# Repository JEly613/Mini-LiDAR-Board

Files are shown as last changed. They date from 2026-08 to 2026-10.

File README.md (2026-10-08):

# Mini-LiDAR-Board

This project fuses data from LiDAR and IMU measurements to reconstruct internal scans of a room. The LiDAR module is mounted on a custom 4-layer PCB that hosts an STM32 microcontroller and an ICM-42688-P IMU. The data from both sensors is collected by the microcontroller and sent via a custom USB protocol to the host software, where the room is reconstructed.

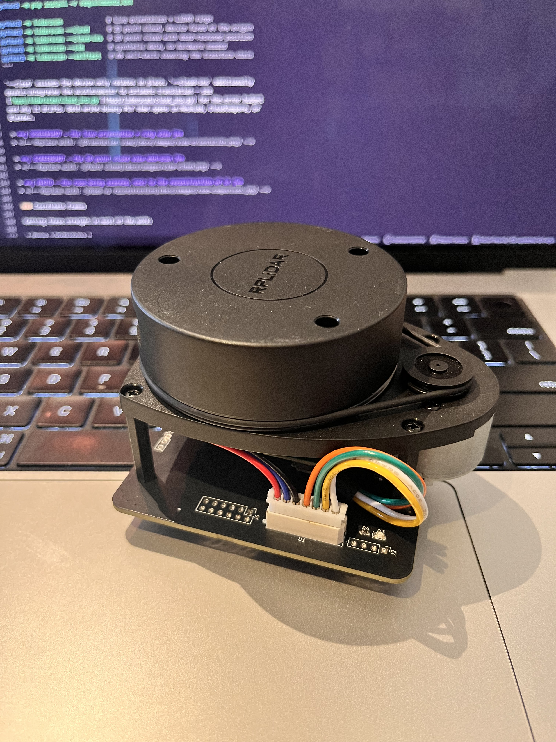
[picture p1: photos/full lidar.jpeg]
The Completed Device


---

## Operation Principle

The board spins a LiDAR module that measures distances in a 2D plane. On its own that only ever produces a flat ring. The on-board IMU tracks how the boardis oriented, so every distance reading can be rotated out of the sensor's 2D plane and into a 3D environment. Tilting the sensor so that all 360 degrees of freedom are covered constructs a full scan of the room.

---

## Hardware

Designed using KiCad.

| | |
|---|---|
| **Board** | 4-layer, 82 × 82 mm, 49 components, 212 vias |
| **Stackup** | `F.Cu` signal · `In1.Cu` GND plane · `In2.Cu` VDD plane · `B.Cu` signal |
| **MCU** | STM32F411CEU6 — QFN-48, 7 × 7 mm, 0.5 mm pitch, 96 MHz |
| **IMU** | TDK ICM-42688-P — LGA-14, 2.5 × 3 mm, on SPI1 |
| **LiDAR** | Slamtec RPLIDAR A1, PWM-driven spindle |
| **Power** | USB-C in, AP2112K-3.3 LDO, 5 V and 3.3 V rails |
| **Clock** | 8 MHz ABM3B crystal → 96 MHz core + exact 48 MHz USB |

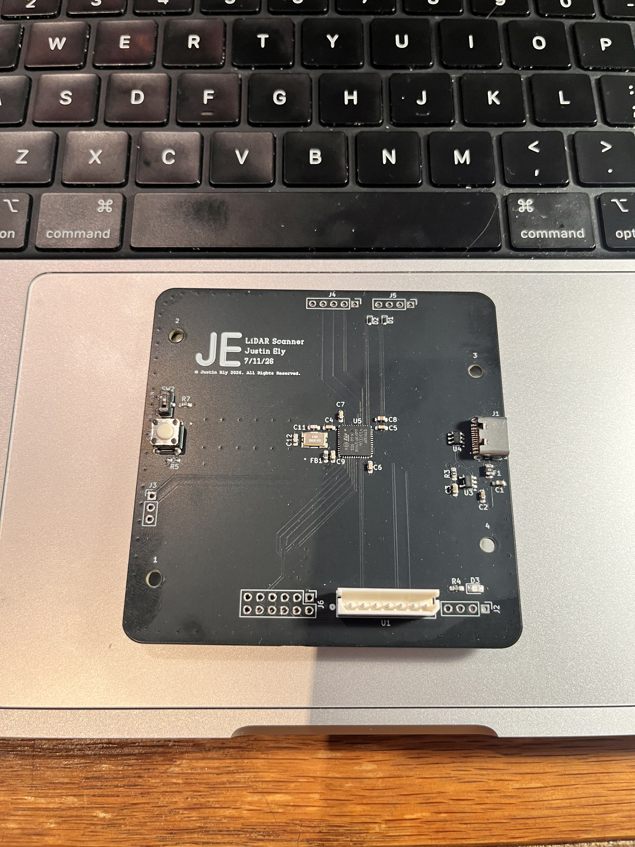
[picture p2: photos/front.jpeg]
Assembled PCB Front Side


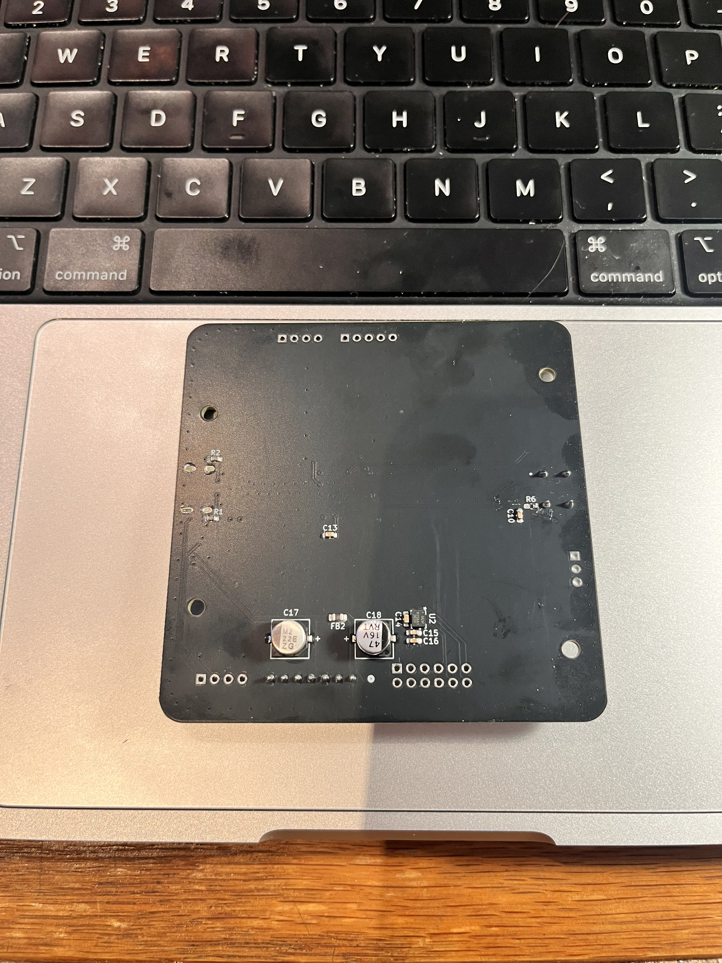
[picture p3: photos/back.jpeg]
Assembled PCB Back Side


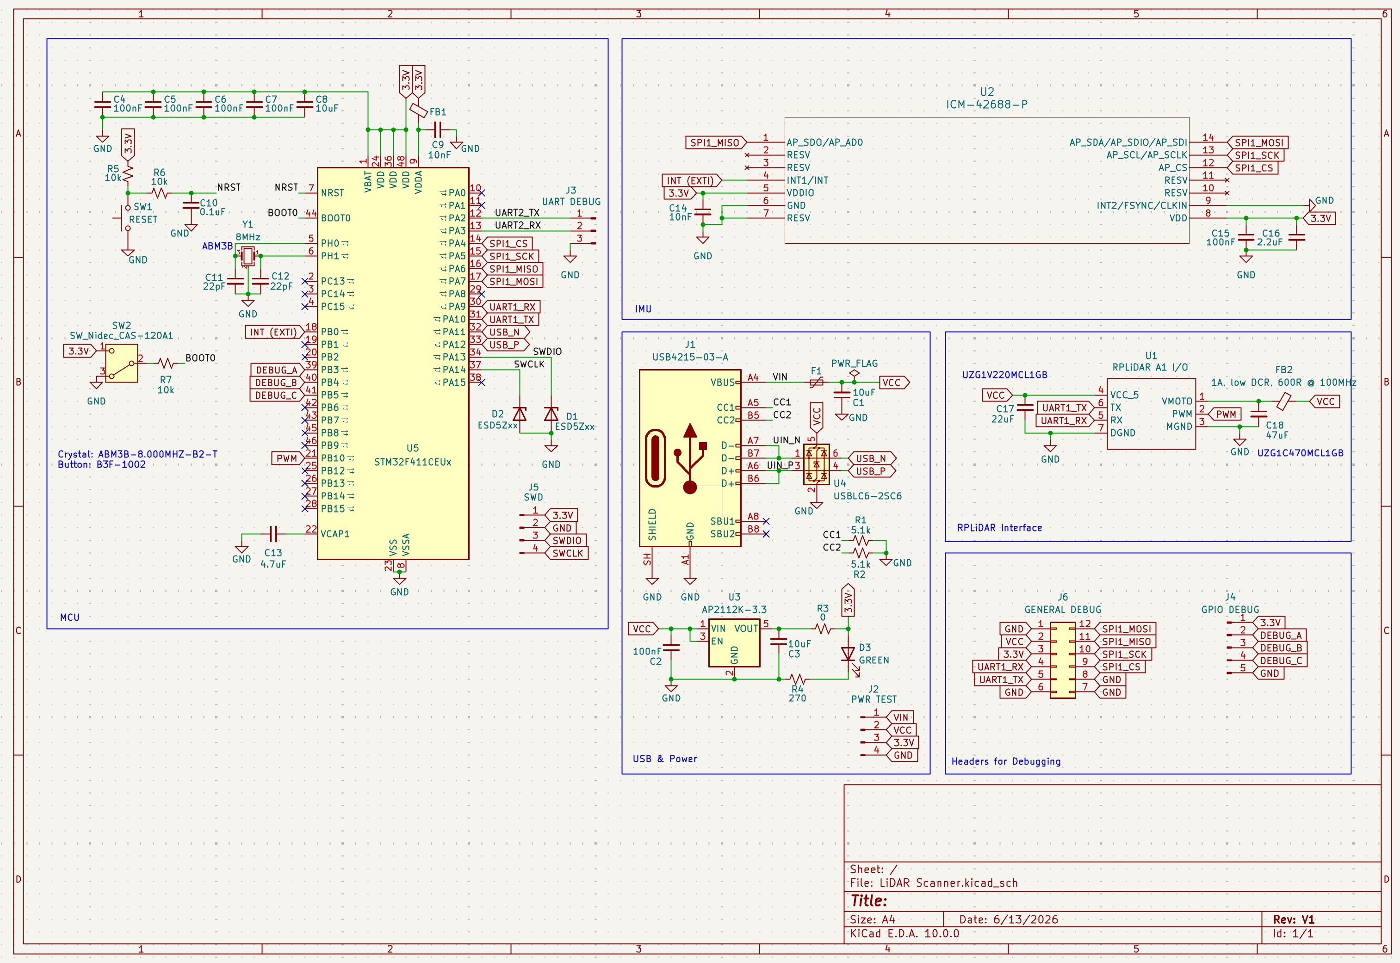
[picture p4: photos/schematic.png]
PCB Schematic


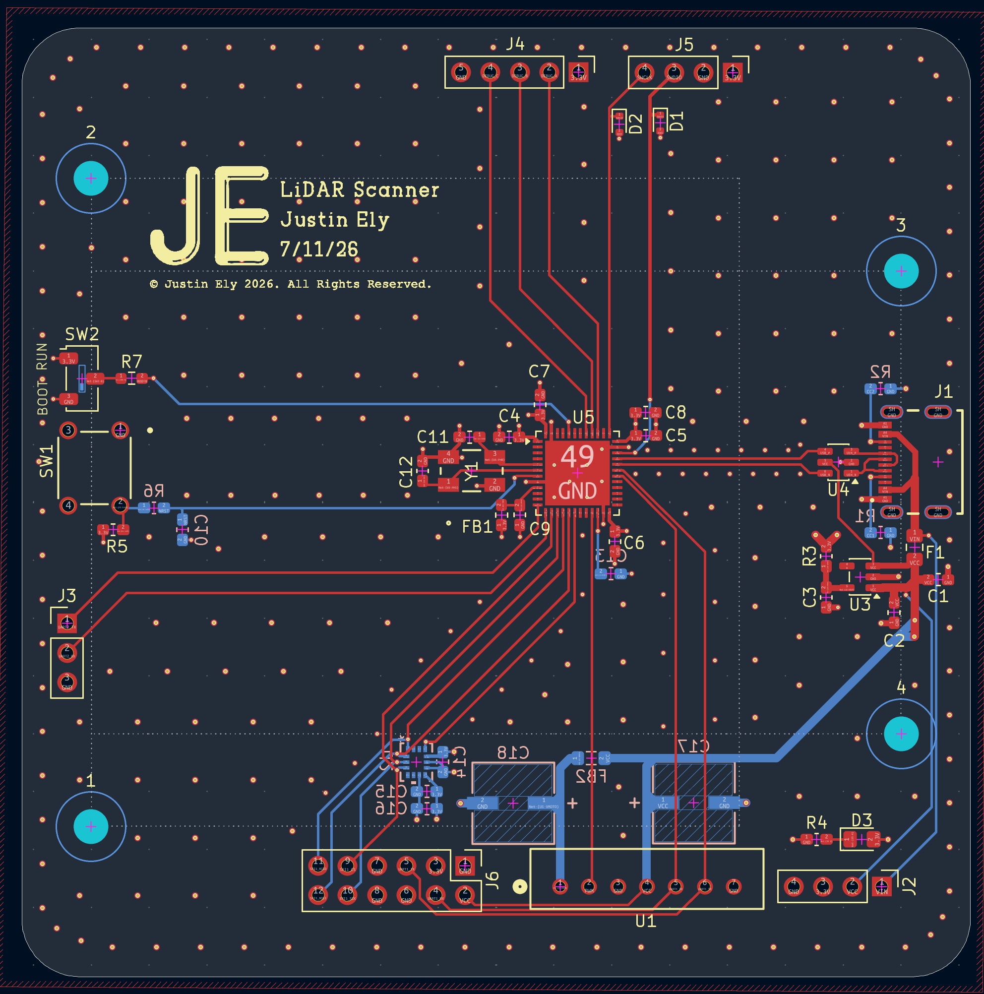
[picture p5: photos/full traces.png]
PCB Layout - Traces


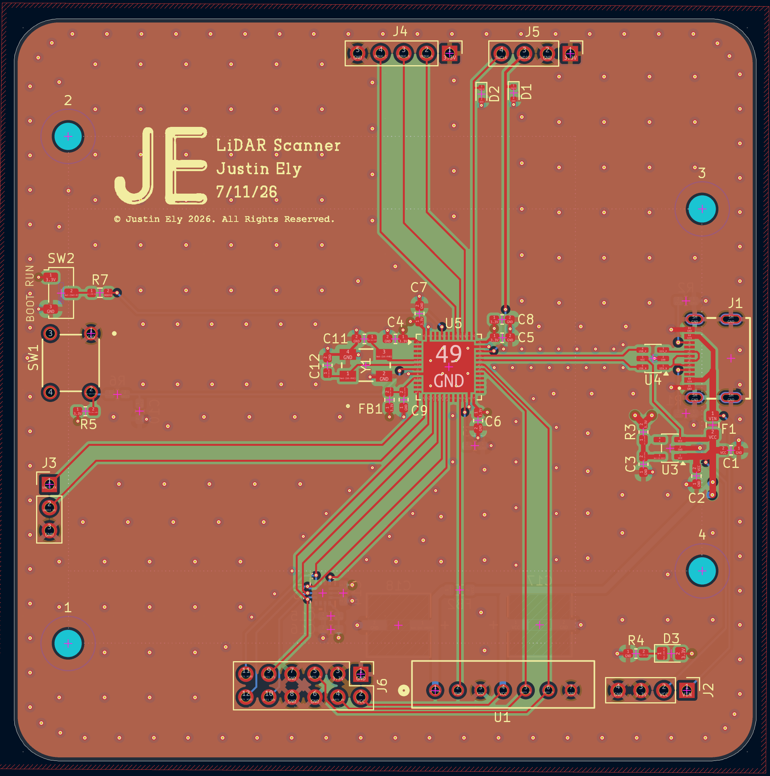
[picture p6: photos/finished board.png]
PCB Layout - Full Stackup


A few notable design decisions:

- **The IMU is mounted on the bottom copper**, rotated −90 degrees. I was worried about the brushed motor on the LiDAR creating noise that would interfere with the IMU, so I shielded it with a few layers of copper. I probably didn't need to but wanted to be safe.
- **The LiDAR motor supply is permanently on** through ferrite bead FB2, with no enable pin. The motor is only driven by the PWM signal, which sometimes causes issues with startup. Next revision I'll add a motor enable.
- **PA9 carries the LiDAR UART**, which means that the MCU can only be flashed through the SWD header.

Gerbers are in:
[`production/`](production/).

---

## Firmware

NOTE: Designed, tested, and validated by me. Implemented with the help of Claude Code.

Register-level bare-metal C with a **12 KB flash image**.

- 96 MHz core from the 8 MHz crystal, with the exact 48 MHz PLLQ that USB needs
- ICM-42688-P at 1 kHz over SPI1 with DMA, triggered by its data-ready interrupt
- 6-DOF Madgwick fusion at the full sample rate, with startup gyro-bias calibration
- RPLIDAR A1 `SCAN` decoding off USART1 with circular DMA and byte-level resync
- TIM2_CH3 PWM spindle control
- CRC-16 framed binary protocol, hardware watchdog, and independent stall
  detection for the IMU, the LiDAR link, and the spindle

Full detail in [`firmware/README.md`](firmware/README.md),
[`firmware/HARDWARE.md`](firmware/HARDWARE.md), and the wire format in
[`firmware/PROTOCOL.md`](firmware/PROTOCOL.md).

### Build and flash

Requires `arm-none-eabi-gcc` and `st-flash` (from stlink-tools).

```bash
cd firmware
make            # builds build/lidar-imu.bin and prints section sizes
make flash      # writes it over SWD
```

---

## Host software

NOTE: Designed, tested, and validated by me. Implemented with the help of Claude Code.

Python 3 with NumPy and matplotlib. Reads the USB CDC stream, parses the binary
protocol, and renders three views.

```bash
cd host
python3 -m pip install -r requirements.txt

python3 -m lidarscan              # live orientation + LiDAR rings
python3 -m lidarscan --cloud      # 3D point cloud, device fixed at the origin
python3 -m lidarscan --cloud-ins  # 3D point cloud with dead-reckoned position
python3 -m lidarscan --sim        # synthetic data, no hardware needed
python3 -m lidarscan --selftest   # 60 self-tests covering the transform chain
```

`--cloud` assumes the device only rotates in place. `--cloud-ins` additionally
double-integrates the accelerometer to estimate translation — see
[`host/lidarscan/cloud_ins.py`](host/lidarscan/cloud_ins.py) for the error budget
and why it drifts. Both write binary PLY that opens in MeshLab, CloudCompare, or
Blender.

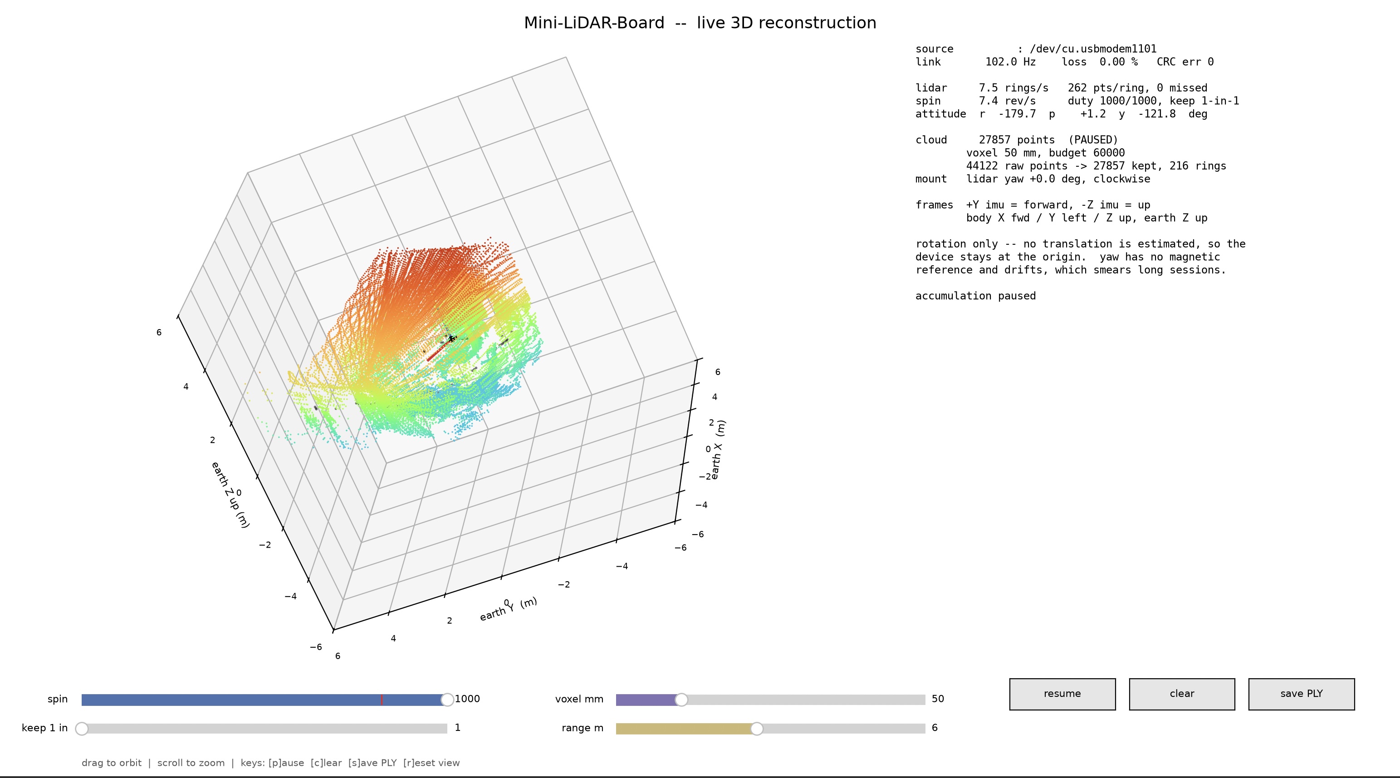
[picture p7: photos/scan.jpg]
Scanning Software


### Coordinate frames

Getting these straight is most of the work:

| Frame | Definition |
|---|---|
| **Sensor** | Raw ICM-42688-P axes. What the Madgwick filter integrates. |
| **Body** | The board: X forward, Y left, Z up. `+Y` sensor is forward, `−Z` sensor is up. |
| **Earth** | Madgwick's output frame, Z up. Yaw has no absolute reference. |
| **LiDAR** | The A1's scan plane, related to the body frame by its physical mounting. |

The A1 is a separate module on a cable, so its orientation relative to the PCB
is mechanical and cannot be known from code. `--lidar-yaw-deg` aligns forward and
`--lidar-ccw` un-mirrors the sweep; set them once for your mounting.

---

## Repository layout

```
firmware/          bare-metal STM32F411 firmware
  src/             16 C source files
  include/         headers, incl. board.h — the authoritative pin map
  cmsis/           vendored ARM CMSIS headers
  PROTOCOL.md      normative wire format
  HARDWARE.md      pin map, DMA allocation, link budget
host/
  lidarscan/       Python host application
    protocol.py    framing, CRC, packet encode/decode
    reader.py      serial + simulated sources
    viz.py         orientation and ring views
    cloud.py       3D reconstruction, rotation only
    cloud_ins.py   3D reconstruction with dead reckoning
production/        gerbers, drill, pick-and-place
docs/images/       photos and screenshots for this README
*.kicad_*          schematic and PCB source
```

---

## Status and known limitations

Working end to end: the board is fabricated, assembled, and validated driving
the IMU, LiDAR, and USB concurrently at 0.00% measured packet loss and 5.6 rev/s
sustained scanning.

Known limits, all understood rather than mysterious:

- **Yaw drifts.** A 6-DOF filter has no magnetic reference, so long sessions
  smear the cloud about the vertical axis. Sweep and look; don't leave it
  accumulating for ten minutes and expect crisp walls.
- **`--cloud-ins` position drifts as t².** Double integration of a MEMS
  accelerometer diverges; zero-velocity updates and bias tracking bound it but
  cannot repeal it. Pause frequently while scanning.
- **Orientation packets are decimated 10:1 without an anti-alias filter**, so
  vibration above 50 Hz aliases into the band the dead-reckoner integrates.
  Averaging the samples in firmware would fix it.
- **The −90° IMU mounting rotation is not separately calibrated** — only the
  Z-flip is handled, via the stated sensor-to-body convention.

---

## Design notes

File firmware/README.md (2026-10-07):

NOTE: Designed, tested, and validated by me. Implemented with the help of Claude Code.

# Mini-LiDAR-Board firmware — IMU orientation + LiDAR rings

Register-level bare-metal C for the STM32F411CEU6 on the custom Mini-LiDAR
scanner board. It reads the on-board ICM-42688-P at 1 kHz, runs a 6-DOF
Madgwick filter, and streams the resulting quaternion to a host over USB
CDC-ACM at ~100 Hz.

It also drives the RPLIDAR A1: TIM2_CH3 PWM on PB10 sets the spindle speed,
USART1 with circular DMA carries the standard `SCAN` stream, and each complete
revolution is forwarded to the host paired with the quaternion at ring-close
time.

**There is no 3D reconstruction in this milestone.** Rings ship in the
sensor's own 2D polar frame. The quaternion travels alongside them, but nothing
rotates anything yet. See [HARDWARE.md](HARDWARE.md).

Host-adjustable at runtime: spindle speed (PWM duty), point decimation, and
scan on/off — see the command table in [PROTOCOL.md](PROTOCOL.md).

Related documents:

* [HARDWARE.md](HARDWARE.md) — verified pin map, IMU quirks, and where the old
  project guide is wrong (**start here**)
* [PROTOCOL.md](PROTOCOL.md) — the binary wire format
* [`../host/`](../host) — the Python visualiser

---

## Requirements

Nothing but the GNU Arm toolchain and `stlink`. No CMake, no STM32Cube, no HAL.
CMSIS core and device headers are vendored into `cmsis/`, so the tree builds
offline.

```
brew install arm-none-eabi-gcc stlink   # already present on this machine
```

The Homebrew `arm-none-eabi-gcc` ships **without newlib**: there is no `libc.a`,
no `<string.h>` and no `<math.h>`. The build is therefore `-ffreestanding
-nostdlib`, `src/util.c` supplies the four `mem*` functions GCC may emit calls
to, and `__builtin_sqrtf` compiles straight to a `VSQRT.F32` instruction, so no
libm is needed.

---

## Build

```
cd firmware
make
```

Produces `build/lidar-imu.elf`, `.bin`, `.hex` and a linker map. The build is
clean under `-Wall -Wextra -Wshadow -Wundef -Wdouble-promotion`.

Other targets:

| target | effect |
|---|---|
| `make flash` | write `build/lidar-imu.bin` to `0x08000000` via `st-flash` and reset |
| `make erase` | full chip erase, if the flash gets into a bad state |
| `make disasm` | annotated disassembly to `build/lidar-imu.lst` |
| `make clean` | remove `build/` |

---

## Wiring the ST-Link to J5

Header **J5** is the SWD port. Pinout, in order:

| J5 pin | signal | ST-Link V2 pin |
|---|---|---|
| 1 | 3V3 | 3.3 V (see note) |
| 2 | GND | GND |
| 3 | SWDIO | SWDIO |
| 4 | SWCLK | SWCLK |

**Note on pin 1.** If the board is powered over its USB-C connector, leave J5.1
disconnected — do not back-feed 3.3 V from the ST-Link into a board that is
already powered. If the board is *not* on USB, connect J5.1 to the ST-Link's
3.3 V output to power it. Never connect J5.1 to the ST-Link's 5 V pin.

Check the probe sees the target before flashing:

```
st-info --probe
```

You should see an `F4` device with 512 KiB of flash. Then:

```
make flash
```

---

## What to expect after flashing

**This board has no GPIO status LEDs.** D3 is a power indicator wired across the
3.3 V rail; the MCU cannot drive it. Nothing blinks. All status is reported over
USB, or on the J4 scope pins.

1. Plug the USB-C cable into a Mac. Within a second or two a serial device
   appears:

   ```
   ls /dev/cu.usbmodem*
   ```

   The device name embeds the STM32's 96-bit unique ID, so two boards on the
   same host get distinct nodes.

2. The firmware immediately sends a `STATUS`/`BOOT` frame, then a
   `STATUS`/`IMU_OK` frame (or an error frame if `WHO_AM_I` did not read
   `0x47`), then `CALIB_START`.

3. **Hold the board still for about two seconds.** It averages 2000 gyro
   samples to measure the zero-rate bias. If it detects motion above 5 °/s it
   retries, up to three times. Then `CALIB_DONE`.

4. From then on it streams `ORIENTATION` frames at ~100 Hz. Run the host app:

   ```
   cd ../host && python3 -m lidarscan
   ```

If you want to see raw bytes rather than run the visualiser, note that the
stream is **binary**, so `cat /dev/cu.usbmodem*` will fill the terminal with
garbage. Use `xxd` or the host app.

### J4 timing pins

Put a logic analyser on J4 to see the firmware's real timing without the USB
link:

| pin | signal | expected |
|---|---|---|
| PB3 | DEBUG_A | toggles on each IMU data-ready → 500 Hz square wave |
| PB4 | DEBUG_B | toggles on each Madgwick update → 500 Hz, phase-shifted from A by the filter latency |
| PB5 | DEBUG_C | toggles on each packet queued → 50 Hz |

If DEBUG_A is flat, the IMU is not asserting INT1. If DEBUG_A runs but DEBUG_B
does not, the main loop is stuck.

### Recovery behaviour

* An independent watchdog (IWDG, ~500 ms nominal) resets the board if the main
  loop stalls. The symptom is the USB serial device disappearing and coming
  back.
* If no IMU data-ready edge arrives for 200 ms, the firmware re-runs
  `icm_init()` and reports `IMU_STALL` then `IMU_RECOVERED`.
* If the 8 MHz crystal fails to start there is no 48 MHz for USB and no way to
  report anything, so the firmware resets. A genuinely dead crystal shows up as
  a boot loop, visible with a scope on PH0.

---

## Source layout

```
firmware/
  Makefile                    plain make, no generator
  stm32f411ce.ld              linker script (512K flash / 128K RAM)
  cmsis/core/                 vendored ARM CMSIS-Core headers
  cmsis/device/               vendored ST device headers (stm32f411xe.h etc.)
  include/, src/
    startup_stm32f411xe.c     vector table + reset entry, written in C
    clock.c                   96 MHz PLL with exact 48 MHz PLLQ for USB
    tim_us.c                  TIM5 as a 32-bit 1 MHz free-running clock
    debug_pins.c              J4 scope pins (the board's only indicators)
    iwdg.c                    independent watchdog
    util.c                    freestanding mem* replacements
    spi1_dma.c                SPI1 + DMA2 Str0/Str3; polled path for config
    icm42688.c                ICM-42688-P driver, EXTI0 data-ready path
    madgwick.c                6-DOF Madgwick filter, runtime-tunable beta
    packet.c                  wire-format serialisers (see PROTOCOL.md)
    pkt_ring.c                frame-granular TX ring, drop-oldest on overflow
    usb_cdc.c                 bare-metal OTG_FS device stack + CDC-ACM class
    main.c                    bring-up, gyro bias calibration, main loop
```

### Interrupt priorities

| priority | source | why |
|---|---|---|
| 1 | EXTI0 (IMU data-ready) | must not be delayed; it only timestamps and starts DMA |
| 1 | DMA2_Stream0 (SPI RX complete) | decodes the sample; same tier as the trigger |
| 3 | OTG_FS | USB can always wait for the IMU, never the other way round |

---

## Verification status

Honest accounting of what has and has not been exercised:

| item | status |
|---|---|
| Compiles and links cleanly, zero warnings under `-Wall -Wextra` | **verified by execution** |
| Flash/RAM footprint fits the part with enormous margin | **verified** (8.6 KiB flash, 5.4 KiB RAM) |
| Register values checked against RM0383 and the ICM-42688-P datasheet | **verified by reading the documents**, not by running |
| Clock tree, SPI/DMA path, IMU configuration, USB CDC enumeration | **written but never run on hardware** |
| Wire format round-trip (firmware layout ↔ host parser) | **verified by execution** — the host test decodes frames byte-identical to the firmware's layout |

The USB CDC stack and the SPI/IMU path are the two places to expect trouble on
first bring-up, in that order.

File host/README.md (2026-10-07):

NOTE: Designed, tested, and validated by me. Implemented with the help of Claude Code.

# Mini-LiDAR-Board host viewer

Live 3D orientation display for the custom Mini-LiDAR scanner board. It opens
the board's USB CDC serial port, parses the binary telemetry stream described in
[`../firmware/PROTOCOL.md`](../firmware/PROTOCOL.md), and draws the board's
current attitude plus roll/pitch/yaw histories and link statistics.

There is **no LiDAR support here yet** — this milestone covers the on-board
ICM-42688-P IMU only. The parser already skips the reserved LiDAR packet types
gracefully, so adding them later will not break anything running today.

---

## Install

numpy and matplotlib are already present in the miniforge3 environment on this
machine. **`pyserial` is the only new dependency**, and it is needed only for
real hardware — `--sim` runs without it:

```
python3 -m pip install pyserial
```

or

```
python3 -m pip install -r requirements.txt
```

Nothing else is required. In particular this app deliberately does **not** use
Open3D, PyQt, pyqtgraph or vispy; none of them are installed, and matplotlib's
3D axes are perfectly adequate here.

---

## Run

```
cd host

python3 -m lidarscan                  # auto-detect /dev/cu.usbmodem*
python3 -m lidarscan --port /dev/cu.usbmodem14201
python3 -m lidarscan --sim            # synthetic data, no hardware needed
python3 -m lidarscan --selftest       # protocol + geometry checks, then exit
```

Useful flags:

| flag | effect |
|---|---|
| `--sim` | synthesise a rotating quaternion instead of reading hardware |
| `--sim-rate HZ` | simulated packet rate (default 100) |
| `--sim-corrupt N` | corrupt every Nth simulated frame, to exercise CRC + resync |
| `--sim-drop N` | drop every Nth simulated frame, to exercise the loss statistic |
| `--duration SECONDS` | exit automatically after this long |
| `--headless` | render with Agg, open no window (works over SSH / in CI) |
| `--save FILE.png` | write a PNG of the final frame |
| `--fps N` | redraw rate, default 30 |
| `--list-ports` | print candidate serial devices and exit |
| `--selftest` | run the built-in checks and exit |

Example that produces a screenshot with no hardware and terminates on its own:

```
python3 -m lidarscan --sim --headless --duration 8 --save shot.png
```

---

## What the display shows

**Left — 3D attitude.** A wireframe of the board (with a wedge marking the
USB-connector end so its heading is unambiguous) plus an RGB body-axis triad:
X red, Y green, Z blue. The grey square is the earth-horizontal plane, so
"level" is obvious at a glance.

**Top right — roll / pitch / yaw** over the last 10 seconds of device time. The
vertical jumps in yaw are the ±180° wrap, not a glitch.

**Bottom right — live statistics:**

| line | meaning |
|---|---|
| `rate` | orientation packets per second, measured over a 1 s sliding window |
| `loss` | derived from gaps in the device's own `sample_count`, not from counting arrivals — so it catches packets that never left the device |
| `dev drops` | frames the *device* discarded because its TX ring overflowed |
| `CRC err / resync / bad hdr` | parser health |
| `quat`, `rpy`, `accel`, `gyro`, `temp` | current sensor state |
| `gyro bias` | `calibrating`, `valid`, or `NOT CALIBRATED` |

Yaw drifts. There is no magnetometer on this board, so the filter is the 6-DOF
IMU-only Madgwick variant: roll and pitch are gravity-referenced and stable,
yaw is dead-reckoned from gyro Z. That is a property of the hardware.

---

## First run with real hardware

1. Flash the board (`cd ../firmware && make flash`) and plug in USB-C.
2. `python3 -m lidarscan --list-ports` should show a `/dev/cu.usbmodem…` node.
   Its suffix embeds the STM32's unique ID, so two boards get distinct names.
3. `python3 -m lidarscan`. The status panel will show `BOOT`, then `IMU_OK`,
   then `CALIB_START`.
4. **Hold the board still for ~2 seconds** while it measures the gyro bias.
   You will see `CALIB_DONE` and `gyro bias: valid`.
5. Pick it up and move it. The 3D board should follow.

If `gyro bias` stays `NOT CALIBRATED`, the board was moving during calibration;
put it down and it will have retried up to three times, or you can power-cycle.

### Troubleshooting

| symptom | likely cause |
|---|---|
| no `/dev/cu.usbmodem*` | board not enumerating — check the USB cable is a data cable, and see the firmware README's notes on the OTG_FS bring-up |
| `IMU_WHO_AM_I_FAIL` in the status log | SPI is working but the part did not answer `0x47` — check U2 orientation and the PA4 chip select |
| `IMU_NO_RESPONSE` | no SPI answer at all — check the IMU's 3.3 V rails and MISO on PA6 |
| high `CRC err` and rising `discarded` | electrical noise or a firmware framing bug; the parser recovers, but the numbers tell you it happened |
| `loss` climbing with `dev drops` climbing | the host is not reading fast enough; close other consumers of the port |
| `loss` climbing with `dev drops` at 0 | packets are being lost on the USB link itself |

---

## Layout

```
host/
  requirements.txt
  lidarscan/
    __init__.py
    __main__.py    CLI, argument parsing, and the built-in self-test
    protocol.py    frame codec + resynchronising parser (from PROTOCOL.md)
    reader.py      background ingestion thread; serial and simulated sources
    viz.py         matplotlib 3D view, time series and statistics panel
```

`protocol.py` and the firmware's `packet.c` are both written from
`firmware/PROTOCOL.md`. They are cross-checked: compiling `packet.c` natively
and feeding its output to `protocol.py` reproduces the values byte-for-byte, and
re-encoding from Python reproduces the firmware's bytes exactly.

---

## Self-test

`python3 -m lidarscan --selftest` runs 18 checks with no hardware:

* the CRC's published check value (`0x29B1` for `"123456789"`);
* frame sizes match `PROTOCOL.md` (68 B orientation, 52 B status);
* encode → parse → decode round-trips;
* resynchronisation past leading garbage;
* a corrupted frame is rejected and the *next* one still accepted;
* byte-at-a-time feeding gives the same result as one big chunk;
* reserved LiDAR packet types are passed through, not treated as corruption;
* a frame split across two reads reassembles;
* the view's rotation matrix is a proper rotation (orthonormal, det +1);
* a +90° yaw maps body X onto earth Y;
* the attitude the view would draw matches the simulator's ground truth to
  within 6e-8.

---

## LiDAR view and controls

The window shows three panels: board attitude in 3D, the current LiDAR
revolution in the sensor's own polar frame, and roll/pitch/yaw over time, plus
a live statistics panel.

**Rings are drawn flat, in the sensor frame.** They are not rotated by the IMU
quaternion — that is the next milestone. The quaternion is carried in every
scan packet already.

Three controls sit along the bottom, and all three change what the *hardware*
does, not just the plot:

| control | effect |
|---|---|
| **spin** | PWM duty on PB10 in permille (0–1000). 0 stops the spindle; below ~250 it stalls rather than turning slowly. |
| **keep 1 in N** | on-device decimation, applied before the packet is built — so it genuinely shrinks the USB traffic. |
| **scan: on/off** | sends the LiDAR `STOP` / `SCAN` command. Does not touch the motor. |

Because the A1's sample rate is fixed (~1954 samples/s measured, capped by the
115200-baud link), spinning slower yields *more* points per revolution rather
than more points per second:

| spin | rings/s | points/ring |
|---|---|---|
| duty 350 | ~2 | ~920 |
| duty 600 | 3.5 | ~550 |
| duty 820 (default) | 5.6 | ~350 |
| duty 900 | 6.2 | ~313 |

600 was the original default and turned out to be marginal — the spindle ran
below its rated speed and eventually stalled during a long session. 820 puts it
on the A1's nominal 5.5 rev/s.

Below ~2 rev/s a revolution exceeds the firmware's 1024-point cap; the plot
then labels the ring `[TRUNCATED]`.

A distance of 0 means "no return" on that ray, not zero range. Those points are
masked out of the plot and counted separately in the caption.

`--sim` synthesises a 4 × 3 m room with a pillar in it, at whatever density the
current simulated spin and decimation imply, so the whole UI including the
controls can be exercised with no hardware attached.

---

## 3D reconstruction (`--cloud`)

```
python3 -m lidarscan --cloud
python3 -m lidarscan --sim --cloud          # no hardware needed
```

Each LiDAR revolution is rotated into world space by the quaternion carried in
that same scan packet — the attitude at the instant the revolution closed — and
accumulated into a voxel-thinned point cloud centred on the device.

**Drag to orbit, scroll to zoom.** Keys: `p` pause accumulation, `c` clear,
`s` save PLY, `r` reset the view. Sliders set spindle speed, decimation, voxel
size and the display cube; buttons pause / clear / save.

### Frames

| frame | definition |
|---|---|
| sensor | raw ICM-42688-P axes; what Madgwick integrates |
| body | **+Y_imu = forward, −Z_imu = up** → X forward, Y left, Z up |
| earth | Madgwick's output frame, Z up. Yaw is free and drifts |

The sensor→body matrix is `[[0,1,0],[1,0,0],[0,0,−1]]` — det +1, so a rotation
and not a mirror. A point at range `d` and angle `θ` becomes
`R_es · M · (d cos θ, d sin θ, 0)`.

### Rotate the device, or you get a flat ring

**No translation is estimated.** The device is assumed to rotate in place, so
it stays at the origin. A stationary board therefore produces exactly one
horizontal ring, no matter how long you leave it running — which is correct,
not a bug. Tilt and sweep the unit to paint a 3D scene.

Measured with the board sitting still and level: 11 797 raw points collapsed to
202 voxels spanning just 108 mm in Z across a 4.2 m radius — a flat disc, as it
should be.

Because yaw has no magnetic reference it drifts, so a long session smears the
cloud about the vertical axis. Sweep and look; don't leave it accumulating for
ten minutes and expect crisp walls.

### Mounting the LiDAR

The A1 is a separate module on a cable, so its orientation relative to the PCB
is a mechanical fact the code cannot know. Two options cover it:

- `--lidar-yaw-deg D` — rotate the scan about the board's up axis until a
  landmark you know is dead ahead appears at the front of the cloud.
- `--lidar-ccw` — flip the sweep direction if the cloud comes out mirrored.

### Keeping it responsive

matplotlib is not a point-cloud engine. `--voxel-mm` (default 50) and
`--max-points` (default 60 000) are what keep the frame rate usable; past
roughly 100 000 points a redraw costs more than the frame interval. Repeated
sweeps of the same wall collapse onto the same voxels, so the cloud stops
growing once the room is covered.

`--save-ply PATH` writes a binary PLY (metres, colour by height) on exit, which
MeshLab, CloudCompare and Blender all open directly.

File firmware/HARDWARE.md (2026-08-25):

# Verified hardware notes — Mini-LiDAR-Board

Everything in this file was read out of the project's KiCad schematic and PCB
(`LiDAR Scanner.kicad_sch`, `LiDAR Scanner.kicad_pcb`) rather than out of
`Lidar Project Guide.md`. **Where the two disagree, this file is right and the
guide is out of date.** The list of disagreements is in the last section.

---

## MCU

| item | value |
|---|---|
| Part | STM32F411CEU6 |
| Package | **UFQFPN-48** (4 mm × 4 mm QFN) |
| Flash / SRAM | 512 KiB / 128 KiB |
| Core | Cortex-M4F, single-precision FPU |
| HSE | 8 MHz crystal Y1 on PH0/PH1, 22 pF load caps |
| LSE | **none fitted** — no 32.768 kHz crystal on this board |
| VCAP1 | pin 22 |

Clock configuration used by this firmware (see `src/clock.c`):

```
HSE 8 MHz -> PLL(M=4, N=192, P=4, Q=8)
  VCO in   2 MHz      (RM0383: must be 1-2 MHz)
  VCO out  384 MHz    (RM0383: must be 100-432 MHz)
  SYSCLK    96 MHz    (F411 limit 100 MHz)
  PLLQ      48 MHz    exact, for USB OTG_FS
AHB /1  ->  HCLK  96 MHz
APB1 /2 ->  PCLK1 48 MHz   (F411 limit 50 MHz), APB1 timers 96 MHz
APB2 /1 ->  PCLK2 96 MHz   (F411 limit 100 MHz)
Flash: 3 wait states, prefetch + I-cache + D-cache on
Power: regulator voltage Scale 1 (required above 84 MHz)
```

---

## Pin map (authoritative)

| Function | Pin | Notes |
|---|---|---|
| IMU SPI1_CS | PA4 | software-controlled GPIO chip select, not hardware NSS |
| IMU SPI1_SCK | PA5 | AF5 |
| IMU SPI1_MISO | PA6 | AF5 |
| IMU SPI1_MOSI | PA7 | AF5 |
| IMU INT1 | **PB0** | EXTI0, data-ready interrupt |
| USB D− | PA11 | USB_OTG_FS, AF10 |
| USB D+ | PA12 | USB_OTG_FS, AF10 |
| SWDIO / SWCLK | PA13 / PA14 | header J5 (1 = 3V3, 2 = GND, 3 = SWDIO, 4 = SWCLK) |
| Debug UART2 TX / RX | PA2 / PA3 | header J3 (1 = TX, 2 = RX, 3 = GND), AF7 |
| DEBUG_A / B / C | PB3 / PB4 / PB5 | header J4, scope/logic-analyser timing pins |
| LiDAR UART1 TX / RX | PA9 / PA10 | **out of scope this milestone — left unconfigured** |
| LiDAR motor PWM | PB10 | TIM2_CH3 — **out of scope, left unconfigured (input, no drive)** |

### PB3 / PB4 are JTAG pins at reset

They come out of reset as JTDO-TRACESWO and NJTRST. Driving them as the J4
timing outputs disables the JTAG-DP. That is harmless here because J5 exposes
**SWD only**, and SWD (PA13/PA14) keeps working. The cost is that SWO trace is
unavailable.

---

## IMU — U2, TDK InvenSense ICM-42688-P, LGA-14

| item | value |
|---|---|
| VDD / VDDIO | both 3.3 V |
| Bus | **SPI only** — there is no I²C to the IMU on this board |
| WHO_AM_I (reg 0x75) | must read `0x47` |
| INT1 | pin 14 → PB0 |
| INT2 / FSYNC / CLKIN (pin 9) | **hard-tied to GND** |
| RESV pin 7 | tied to GND |
| RESV pins 2, 3, 10, 11 | unconnected |

### Consequences of pin 9 being grounded

1. **INT2 and FSYNC are unavailable.** INT1 on PB0 is the only interrupt path.
2. INT2 must never be configured as a push-pull output — it would drive into a
   ground short. `src/icm42688.c` leaves the INT2 half of `INT_CONFIG` (bits
   5:3) at its reset value: open drain, active low.
3. `TMST_CONFIG.TMST_FSYNC_EN` comes out of reset **set**, which makes the part
   interpret the grounded pin as an FSYNC input and overwrite the low byte of
   gyro X with an FSYNC timestamp. The firmware explicitly clears it during
   init. This is easy to miss and produces a subtly wrong gyro X axis.

### Other datasheet details the driver depends on

* `INT_CONFIG1` bit 4 `INT_ASYNC_RESET` comes out of reset **set**, and the
  datasheet instructs the user to clear it "for proper INT1 and INT2 pin
  operation". Left at 1, interrupt pulses go missing. The firmware writes
  `INT_CONFIG1 = 0x00`.
* After writing `PWR_MGMT0`, no register write may be issued for 200 µs; the
  gyro additionally needs up to ~30 ms to start.
* Sensitivity at the configured ranges: gyro ±500 dps → 65.5 LSB/dps;
  accel ±8 g → 4096 LSB/g; temperature → `°C = raw/132.48 + 25`.
* Maximum SPI clock is 24 MHz. The firmware uses ~1.5 MHz for configuration
  writes and 12 MHz for the data burst.

---

## THERE ARE NO GPIO STATUS LEDs

This is the single most important thing to know before writing firmware for
this board.

* **D3 is a green power LED wired directly across the 3.3 V rail through R4.**
  It has no MCU connection whatsoever. It is on whenever the board has power.
* There is no IMU LED, no LIDAR LED and no STATUS LED, despite what the project
  guide describes. They were never built.

Every piece of firmware state must therefore be reported either:

1. over the USB data link, as a `STATUS` packet (see `PROTOCOL.md`), or
2. as an edge on DEBUG_A/B/C (PB3/PB4/PB5, header J4) for a scope or logic
   analyser.

There is no blink code anywhere in this project, and there cannot be. Any
future contributor who "adds an LED heartbeat" is writing to a pin that does
not exist.

---

## DMA allocation and the reservation for LiDAR

On the STM32F411 (RM0383 Table 28, DMA2 request mapping):

```
SPI1_RX   : DMA2 Stream 0 ch 3   or   DMA2 Stream 2 ch 3
SPI1_TX   : DMA2 Stream 3 ch 3   or   DMA2 Stream 5 ch 3
USART1_RX : DMA2 Stream 2 ch 4   or   DMA2 Stream 5 ch 4
```

USART1_RX — which the LiDAR will need, because an RPLIDAR pushes a continuous
scan stream that cannot be serviced byte-by-byte alongside a 1 kHz IMU — can
only live on Stream 2 or Stream 5. This firmware therefore takes **Stream 0 for
SPI1_RX and Stream 3 for SPI1_TX**, leaving both USART1_RX options free.
Choosing Stream 2 or Stream 5 for SPI would work fine today and force a rework
later.

---

## Deviations from `Lidar Project Guide.md`

| The guide says | Reality |
|---|---|
| MCU is in an **LQFP48** package | It is **UFQFPN-48** |
| IMU INT2 / FSYNC usable | Pin 9 is **hard-tied to GND**; INT2 and FSYNC do not exist on this board |
| IMU, LIDAR and STATUS **LEDs** on GPIOs | **No GPIO LEDs exist.** D3 is a power-rail-only indicator with no MCU connection |
| — | The guide does not mention that `TMST_CONFIG.TMST_FSYNC_EN` must be cleared because of the grounded FSYNC pin |

Do not "fix" the firmware to match the guide.

---

## LiDAR wiring (added in the LiDAR milestone)

Connector **U1** (Molex 22035075) carries the RPLIDAR A1:

| U1 pin | net | goes to | note |
|---|---|---|---|
| 1 | `Net-(U1-VMOTO)` | 5 V via ferrite bead **FB2**, 47 µF bulk (C18) | motor supply |
| 2 | `PWM` | **PB10**, TIM2_CH3, AF1 | spindle speed |
| 3 | `MGND` | GND | motor ground |
| 4 | `VCC` | 5 V via polyfuse F1 | logic supply |
| 5 | `UART1_RX` | **PA9** = USART1_**TX** | MCU → LiDAR |
| 6 | `UART1_TX` | **PA10** = USART1_**RX** | LiDAR → MCU |
| 7 | `DGND` | GND | |

Three things here differ from the project guide and matter for firmware:

1. **There is no motor enable GPIO and no LiDAR enable jumper.** VMOTO is
   hard-wired to 5 V through FB2, so the spindle is powered whenever the board
   is. PWM duty on PB10 is the *only* control over the motor; 0 % is the only
   way to stop it. The guide describes a solder jumper on a "motor enable GPIO
   line" — it was never built.

2. **The UART net names are from the LiDAR's point of view.** The net called
   `UART1_RX` lands on PA9, which is USART1_**TX**. The wiring is correct; only
   the labels invite a mis-read.

3. **PA9 is also the OTG_FS VBUS sense pin**, and it is used for the LiDAR
   UART here. `GCCFG.NOVBUSSENS` must stay set or USB will not enumerate. This
   was already true before the LiDAR existed, but it is now load-bearing for
   two subsystems rather than one.

### Link budget

The A1 runs at 115200 baud and standard `SCAN` mode spends 5 bytes per
measurement, so the wire caps out at ~2300 samples/s no matter what the sensor
can do internally. Measured on this board: **1954 samples/s**. Spindle speed
therefore trades rings/s against points/ring:

| PWM duty | measured spin | points/ring |
|---|---|---|
| 350 | ~2 rev/s | ~920 |
| 600 | 3.5 rev/s | ~550 |
| 820 (default) | 5.6 rev/s | ~350 |
| 900 | 6.2 rev/s | ~313 |

The default was originally 600. That runs the spindle well below its rated
5.5 rev/s, and during a long session it stalled outright — hence 820.

### Two different LiDAR stalls

Worth knowing because they need different watchdogs, and only one of them is
obvious:

1. **The device goes quiet.** No measurement nodes arrive. Caught by watching
   `rplidar_last_node_us()`.
2. **The spindle stops but the device keeps talking.** The A1 goes on streaming
   measurement nodes at a frozen angle, so the node watchdog stays happy
   forever while no revolution ever closes. This is the one that actually bit
   us. Caught separately by watching `rplidar_last_ring_us()`.

Recovery for (2) kicks the motor to full duty for 400 ms before restoring the
commanded duty — static friction takes more torque to break than rotation takes
to sustain — then re-arms the UART DMA and restarts the scan.

Below about 2 rev/s a revolution exceeds the firmware's 1024-point cap and the
ring is truncated (flagged, not silent).

### DMA map

| request | stream | why |
|---|---|---|
| SPI1_RX | DMA2 Stream 0 ch 3 | leaves both USART1_RX options free |
| SPI1_TX | DMA2 Stream 3 ch 3 | |
| USART1_RX | DMA2 Stream 5 ch 4 | circular, never serviced on a deadline |

USART1_RX can only live on Stream 2 or Stream 5, and SPI1_RX only on Stream 0
or Stream 2. Putting SPI1 on Stream 0 during the IMU milestone is what made
this conflict-free; Stream 2 is still spare.

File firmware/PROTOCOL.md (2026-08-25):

# Mini-LiDAR-Board wire protocol v1

This document is the **normative** definition of the binary link between the
board and the host. Both implementations are written from this table:

| Side | File |
|---|---|
| Firmware serialiser | `firmware/src/packet.c`, `firmware/include/packet.h` |
| Host parser | `host/lidarscan/protocol.py` |

If you change the format, change all three, and bump `version`.

The transport is a USB CDC-ACM (virtual serial) link. It is a **byte stream**,
not a message-oriented one — USB packet boundaries are not frame boundaries, so
the parser must find frames by scanning for the sync pattern and validating the
CRC. Never assume one read returns exactly one frame.

---

## 1. Frame layout

```
 offset  size  field      description
 ------  ----  ---------  ------------------------------------------------
      0     1  sync0      0xA5
      1     1  sync1      0x5A
      2     1  version    0x01 for this document
      3     1  type       see section 2
      4     2  length     payload length in bytes (uint16)
      6     N  payload    type-specific, N == length
    6+N     2  crc16      CRC-16/CCITT-FALSE over bytes [2 .. 6+N-1]
```

Total frame size is `8 + length`.

### Endianness

**Everything multi-byte is little-endian.** That includes `length`, `crc16`, all
integers in payloads, and all `float32` values (IEEE-754 binary32, stored
little-endian — i.e. what `struct.unpack('<f', ...)` reads and what a
Cortex-M4 or an x86/ARM host stores natively). No field anywhere in this
protocol is big-endian.

(The ICM-42688-P itself delivers big-endian sensor words on the SPI bus. That
is a detail entirely internal to the firmware; nothing big-endian reaches the
wire.)

### Checksum

CRC-16/CCITT-FALSE, also catalogued as CRC-16/IBM-3740:

| parameter | value |
|---|---|
| polynomial | `0x1021` |
| initial value | `0xFFFF` |
| input reflected | no |
| output reflected | no |
| final XOR | `0x0000` |

It covers `version`, `type`, `length` and the payload — bytes 2 through
`6+N-1` — but **not** the two sync bytes. The sync bytes are a resynchronisation
marker rather than data; including them would add nothing, whereas covering
`length` means a corrupted length can never make a receiver accept a mis-sized
frame.

### Parsing rules

1. Scan for `A5 5A`.
2. Read the 4 remaining header bytes. Reject (and resume scanning from the byte
   after `sync0`) if `version != 0x01` or `length > 128`.
3. Wait for `length + 2` more bytes.
4. Verify the CRC. On mismatch, discard and resume scanning from the byte after
   `sync0` — a false sync inside a payload is the normal cause.
5. Dispatch on `type`. **Unknown types must be skipped, not treated as an
   error**: that is what makes the format extensible.

---

## 2. Packet types

| range | direction | meaning |
|---|---|---|
| `0x01`–`0x0F` | device → host | IMU / orientation telemetry (this milestone) |
| `0x10`–`0x1F` | device → host | **reserved for LiDAR**, not implemented |
| `0x80`–`0x8F` | host → device | commands |

Assigned:

| type | name | payload | frame |
|---|---|---|---|
| `0x01` | `ORIENTATION` | 60 B | 68 B |
| `0x02` | `STATUS` | 44 B | 52 B |
| `0x10` | `LIDAR_SCAN` — **reserved, unimplemented** | — | — |
| `0x11` | `LIDAR_POINT` — **reserved, unimplemented** | — | — |
| `0x80` | `CMD_SET_BETA` | 4 B | 12 B |
| `0x81` | `CMD_RECALIBRATE` | 0 B | 8 B |
| `0x82` | `CMD_PING` | 0 B | 8 B |

Nothing in this firmware emits or parses `0x10`/`0x11`. They exist so that the
numbering is settled before a second data stream is added, and so the host
parser can already be written to ignore them gracefully.

---

## 3. `0x01` ORIENTATION — 60-byte payload

Emitted at ~100 Hz (every 10th 1 kHz filter update).

| offset | type | field | units / notes |
|---|---|---|---|
| 0 | `uint32` | `t_us` | device timestamp of the IMU sample, microseconds |
| 4 | `float32` | `q0` | quaternion scalar part (w) |
| 8 | `float32` | `q1` | quaternion x |
| 12 | `float32` | `q2` | quaternion y |
| 16 | `float32` | `q3` | quaternion z |
| 20 | `float32` | `ax` | accelerometer X, **g** |
| 24 | `float32` | `ay` | accelerometer Y, g |
| 28 | `float32` | `az` | accelerometer Z, g |
| 32 | `float32` | `gx` | gyroscope X, **deg/s**, bias removed |
| 36 | `float32` | `gy` | gyroscope Y, deg/s, bias removed |
| 40 | `float32` | `gz` | gyroscope Z, deg/s, bias removed |
| 44 | `float32` | `temp_c` | IMU die temperature, °C |
| 48 | `uint32` | `sample_count` | IMU samples read since boot |
| 52 | `uint32` | `drop_count` | frames discarded by the TX ring buffer |
| 56 | `uint16` | `imu_odr_hz` | configured IMU output data rate (1000) |
| 58 | `uint8` | `flags` | see section 5 |
| 59 | `uint8` | *reserved* | always 0 |

The quaternion is a **unit** quaternion describing the rotation from the sensor
frame to the earth frame, in Madgwick's `(w, x, y, z)` order.

### Timestamps

`t_us` comes from a free-running 32-bit 1 MHz timer (TIM5). It **wraps every
2³² µs ≈ 4295 s ≈ 71.6 minutes**. Hosts that need a monotonic timeline must
unwrap it themselves; the reference host parser does, by adding 2³² whenever a
timestamp goes backwards.

### Drift caveat

There is no magnetometer on this board, so the filter is the 6-DOF IMU-only
Madgwick variant. Roll and pitch are gravity-referenced and drift-free. **Yaw is
dead-reckoned from gyro Z and will drift** — typically a few degrees per minute
after bias calibration. This is a property of the sensor set, not a bug.

---

## 4. `0x02` STATUS — 44-byte payload

Emitted asynchronously on boot, on IMU init success/failure, around gyro
calibration, on stall detection and recovery, and in reply to `CMD_PING`.

| offset | type | field | notes |
|---|---|---|---|
| 0 | `uint32` | `t_us` | device timestamp, microseconds |
| 4 | `uint32` | `uptime_ms` | milliseconds since boot |
| 8 | `uint8` | `code` | see below |
| 9 | `uint8` | `who_am_i` | last WHO_AM_I byte read from the IMU (0x47 = OK) |
| 10 | `uint8` | `flags` | see section 5 |
| 11 | `uint8` | *reserved* | always 0 |
| 12 | `char[32]` | `msg` | NUL-padded ASCII, **not guaranteed NUL-terminated** |

Status codes:

| code | name | meaning |
|---|---|---|
| 0 | `BOOT` | clocks and USB are up |
| 1 | `IMU_OK` | ICM-42688-P identified and configured |
| 2 | `IMU_WHO_AM_I_FAIL` | device answered, but not with `0x47` |
| 3 | `IMU_NO_RESPONSE` | SPI reads returned only `0x00`/`0xFF` |
| 4 | `CALIB_START` | gyro bias calibration beginning (hold still) |
| 5 | `CALIB_DONE` | bias captured |
| 6 | `IMU_STALL` | no data-ready edge for 200 ms |
| 7 | `IMU_RECOVERED` | IMU re-initialised after a stall |
| 8 | `PONG` | reply to `CMD_PING` |
| 9 | `BETA_CHANGED` | filter gain updated |

---

## 5. Flags byte

Present in both `ORIENTATION` and `STATUS`.

| bit | mask | name | meaning |
|---|---|---|---|
| 0 | `0x01` | `IMU_OK` | IMU identified and streaming |
| 1 | `0x02` | `BIAS_VALID` | gyro bias calibration completed successfully |
| 2 | `0x04` | `USB_CONFIGURED` | host has issued SET_CONFIGURATION |
| 3 | `0x08` | `CALIBRATING` | bias calibration in progress / never completed |
| 4 | `0x10` | `STALL_RECOVERED` | at least one IMU stall recovery has occurred |

---

## 6. Host → device commands

Same framing. The firmware validates sync, version, length and CRC, and
silently ignores anything that fails or that carries an unknown type. Commands
must arrive as a single USB packet (≤ 64 bytes), which every command in this
version comfortably satisfies.

| type | name | payload |
|---|---|---|
| `0x80` | `CMD_SET_BETA` | `float32` — new Madgwick gain, accepted if `0 ≤ β ≤ 10` and not NaN |
| `0x81` | `CMD_RECALIBRATE` | none — restarts gyro bias calibration; hold the board still |
| `0x82` | `CMD_PING` | none — answered with a `STATUS`/`PONG` |
| `0x83` | `CMD_SET_MOTOR` | `uint16` — spindle PWM duty in permille, 0…1000. 0 stops the motor; below ~250 it stalls rather than turning slowly |
| `0x84` | `CMD_SET_DECIM` | `uint8` — keep 1 LiDAR point in N, 1…16. Applied on the device, before the packet is built |
| `0x85` | `CMD_LIDAR_ENABLE` | `uint8` — 0 sends the LiDAR `STOP` command, 1 re-runs health check + `SCAN`. Does not touch the motor |

---

## 7. LiDAR scan packet — type `0x10`

One packet per complete revolution of the RPLIDAR A1. A fixed 40-byte header
followed by `point_count` × 4 bytes, so the frame length is variable and the
reader must size the point array from `point_count`.

| off | size | field | notes |
|---|---|---|---|
| 0 | 4 | `t_us` | device microseconds when the revolution closed |
| 4 | 4 | `seq` | revolutions since scanning started; gaps mean lost packets |
| 8 | 16 | `q[4]` | `float32` w, x, y, z — board attitude at `t_us` |
| 24 | 4 | `rot_hz` | `float32`, measured spindle rate |
| 28 | 4 | `sample_hz` | `float32`, measured points/s **before** decimation |
| 32 | 2 | `point_count` | number of points that follow |
| 34 | 2 | `motor_permille` | PWM duty currently commanded |
| 36 | 1 | `decimation` | keep-1-in-N currently applied |
| 37 | 1 | `flags` | see the flag table |
| 38 | 2 | reserved | zero |
| 40 | 4×N | points | `uint16 angle_q6`, `uint16 dist_mm` |

`angle_q6` is degrees × 64 (so 0…23039). `dist_mm` is millimetres, and **0
means "no return"** on that ray — out of range or absorbed — not "zero
distance". A reader that plots zeros draws a bogus blob at the origin.

The quaternion is carried but **nothing rotates the ring by it yet**. This
milestone displays the two streams side by side. Pairing them here, at the one
place where both timestamps are known exactly, is what lets the later 3D stage
be a rotation rather than a re-derivation.

Largest legal frame: 8 + 40 + 1024 × 4 = **4152 bytes**.

### What is actually adjustable

The A1 has no command to change its internal measurement rate in standard
`SCAN` mode, and the 115200-baud link caps the wire at ~2300 samples/s (5 bytes
per sample) regardless. So `sample_hz` is roughly constant, and what the
operator really controls is:

- **spindle speed** (`CMD_SET_MOTOR`) — slower spin means *more* points per
  revolution, because the sample rate is fixed;
- **decimation** (`CMD_SET_DECIM`) — thins the points actually sent.

Below roughly 2 rev/s a revolution exceeds the 1024-point cap; the ring is
truncated and `FLAG_SCAN_TRUNCATED` is set rather than the length silently
disagreeing.

---

## 8. Flow control and loss

The firmware never blocks on USB. Frames go into a 16 KiB ring buffer that the
USB IN-endpoint interrupt drains. If the host stops reading, the ring fills and
**the oldest whole frames are discarded**; `drop_count` in the next
`ORIENTATION` packet reports the running total.

Push and discard are frame-granular, so an overflow never truncates a frame.
The *drain* is a byte stream: a scan frame is several times larger than one USB
transfer (192 bytes), so it is handed to the endpoint in pieces. That is
invisible to the host, which frames on the sync bytes plus CRC. The single
exception to "drop the oldest" is a frame that is already part-way out of the
endpoint — discarding that one would hand the host a fragment, so the incoming
frame is dropped instead.

Because the device is free-running, the host should treat a gap in
`sample_count` (which advances by ~10 per orientation packet) as the ground
truth for loss, rather than counting received packets alone.

One caveat: the firmware stamps the **live** `icm_sample_count()` when it
builds a packet, not the index of the sample it is processing, so when the main
loop drains a backlog the step jitters by a few counts around 10. A host
inferring the decimation from the stream must use the *most common* step, not
the smallest — a minimum-based estimate latches onto the first outlier and then
reports a large permanent loss that is not real.

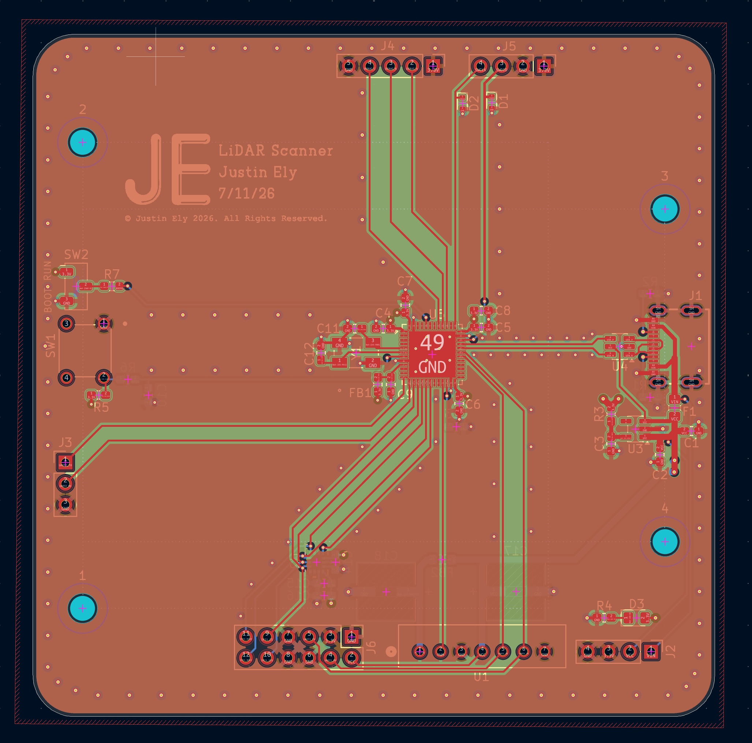
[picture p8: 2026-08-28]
photos/full stackup.jpg

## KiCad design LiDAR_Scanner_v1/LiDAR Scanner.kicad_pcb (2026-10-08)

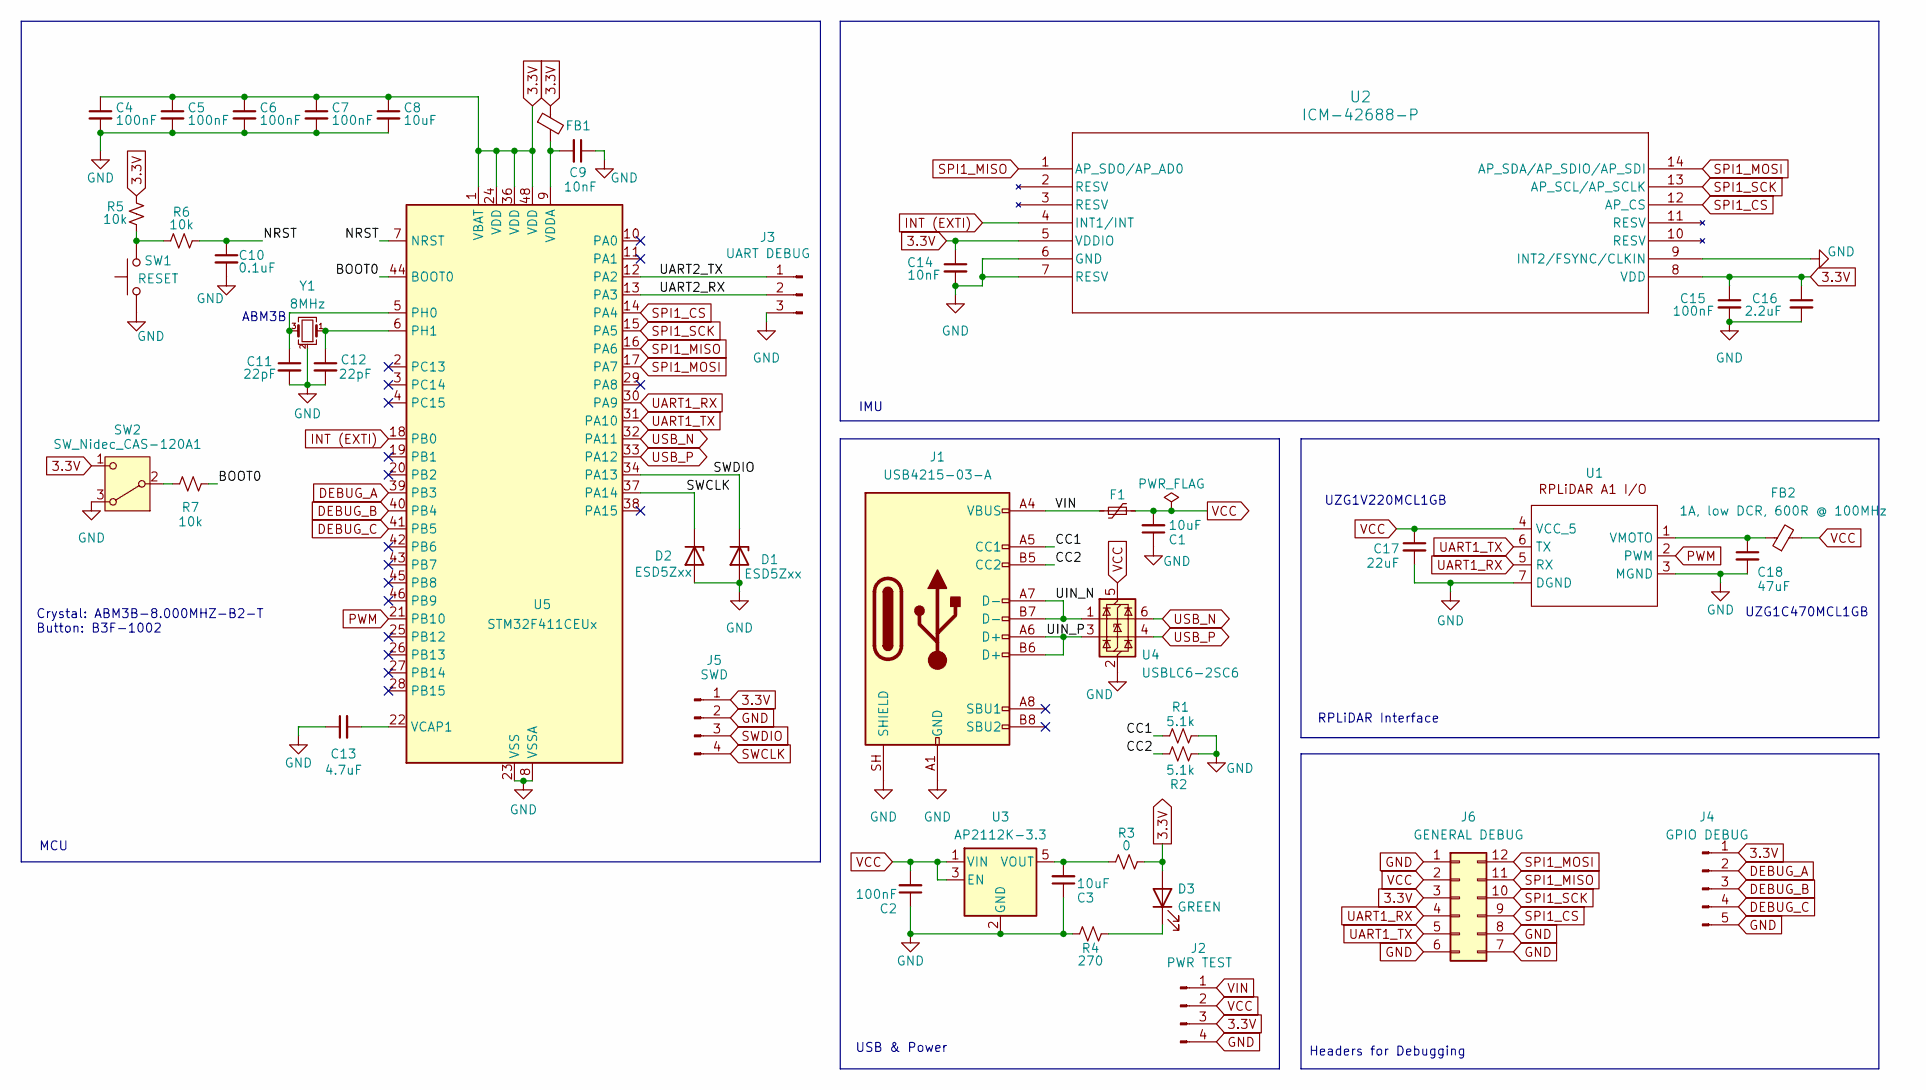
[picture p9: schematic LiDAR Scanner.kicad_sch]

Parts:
C1, C3, C8: 10uF; C_0603_1608Metric_Pad1.08x0.95mm_HandSolder
C2, C4, C5, C6, C7, C15: 100nF; C_0603_1608Metric_Pad1.08x0.95mm_HandSolder
C9, C14: 10nF; C_0603_1608Metric_Pad1.08x0.95mm_HandSolder
C10: 0.1uF; C_0603_1608Metric_Pad1.08x0.95mm_HandSolder
C11, C12: 22pF; C_0603_1608Metric_Pad1.08x0.95mm_HandSolder
C13: 4.7uF; C_0603_1608Metric_Pad1.08x0.95mm_HandSolder
C16: 2.2uF; C_0603_1608Metric_Pad1.08x0.95mm_HandSolder
C17: 22uF; PCAP_6.3x3-ELECT_NCA-L
C18: 47uF; PCAP_6.3x3-ELECT_NCA-L
D1, D2: ESD5Zxx; D_SOD-523
D3: GREEN; LED_0805_2012Metric_Pad1.15x1.40mm_HandSolder
F1: Polyfuse_Small; Fuse_0805_2012Metric_Pad1.15x1.40mm_HandSolder
FB1: FerriteBead_Small; L_0603_1608Metric_Pad1.05x0.95mm_HandSolder
FB2: 1A, low DCR, 600R @ 100MHz; L_0805_2012Metric_Pad1.05x1.20mm_HandSolder
J1: USB4215-03-A; GCT_USB4215-03-A_REVA
J2: PWR TEST; PinHeader_1x04_P2.54mm_Vertical
J3: UART DEBUG; PinHeader_1x03_P2.54mm_Vertical
J4: GPIO DEBUG; PinHeader_1x05_P2.54mm_Vertical
J5: SWD; PinHeader_1x04_P2.54mm_Vertical
J6: GENERAL DEBUG; PinHeader_2x06_P2.54mm_Vertical
R1, R2: 5.1k; C_0603_1608Metric_Pad1.08x0.95mm_HandSolder
R3: 0; C_0603_1608Metric_Pad1.08x0.95mm_HandSolder
R4: 270; C_0603_1608Metric_Pad1.08x0.95mm_HandSolder
R5, R6: 10k; C_0603_1608Metric_Pad1.08x0.95mm_HandSolder
R7: 10k; R_0603_1608Metric_Pad0.98x0.95mm_HandSolder
SW1: RESET; SW_B3F-1000_OMR
SW2: SW_Nidec_CAS-120A1; Nidec_Copal_CAS-120A
U1: CONN_22035075_MOL
U2: ICM-42688-P; LGA14_2P5X3X0P91_TDK
U3: AP2112K-3.3; SOT-23-5
U4: USBLC6-2SC6; SOT-23-6
U5: STM32F411CEUx; QFN-48-1EP_7x7mm_P0.5mm_EP5.6x5.6mm
Y1: 8MHz; ABM3B_ABR

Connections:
3.3V: C4.1, C5.1, C6.1, C7.1, C8.1, C14.1, C15.1, C16.1, D3.2 (A), FB1.1, J2.3, J4.1, J5.1, J6.3, R3.2, R5.1, SW2.1 (C), U2.5 (VDDIO), U2.8 (VDD), U5.1 (VBAT), U5.24 (VDD), U5.36 (VDD), U5.48 (VDD)
/BOOT0: R7.2, U5.44 (BOOT0)
/CC1: J1.A5 (CC1), R1.2
/CC2: J1.B5 (CC2), R2.2
/NRST: C10.1, R6.2, U5.7 (NRST)
/UART2_RX: J3.2, U5.13 (PA3)
/UART2_TX: J3.1, U5.12 (PA2)
/UIN_N: J1.A7 (D-), J1.B7 (D-), U4.1 (I/O1)
/UIN_P: J1.A6 (D+), J1.B6 (D+), U4.3 (I/O2)
DEBUG_A: J4.2, U5.39 (PB3)
DEBUG_B: J4.3, U5.40 (PB4)
DEBUG_C: J4.4, U5.41 (PB5)
GND: C1.1, C2.1, C3.1, C4.2, C5.2, C6.2, C7.2, C8.2, C9.1, C10.2, C11.2, C12.2, C13.1, C14.2, C15.2, C16.2, C17.2, C18.2, D1.2 (A), D2.2 (A), J1.A1 (GND), J1.A12 (GND), J1.B1 (GND), J1.B12 (GND), J1.SH (SHIELD), J2.4, J3.3, J4.5, J5.2, J6.1, J6.6, J6.7, J6.8, R1.1, R2.1, R4.1, SW1.1, SW2.3 (A), U1.3 (MGND), U1.7 (DGND), U2.6 (GND), U2.7 (RESV), U2.9 (INT2/FSYNC/CLKIN), U3.2 (GND), U4.2 (GND), U5.8 (VSSA), U5.23 (VSS), U5.35 (VSS), U5.47 (VSS), U5.49 (VSS), Y1.2 (G), Y1.4 (G)
INT (EXTI): U2.4 (INT1/INT), U5.18 (PB0)
unnamed: D3.1 (K), R4.2
unnamed: R5.2, R6.1, SW1.2
unnamed: R7.1, SW2.2 (B)
unnamed: C18.1, FB2.1, U1.1 (VMOTO)
unnamed: C3.2, R3.1, U3.5 (VOUT)
unnamed: C11.1, U5.5 (PH0), Y1.3
unnamed: C12.1, U5.6 (PH1), Y1.1
unnamed: C13.2, U5.22 (VCAP1)
unnamed: C9.2, FB1.2, U5.9 (VDDA)
PWM: U1.2 (PWM), U5.21 (PB10)
SPI1_CS: J6.9, U2.12 (AP_CS), U5.14 (PA4)
SPI1_MISO: J6.11, U2.1 (AP_SDO/AP_AD0), U5.16 (PA6)
SPI1_MOSI: J6.12, U2.14 (AP_SDA/AP_SDIO/AP_SDI), U5.17 (PA7)
SPI1_SCK: J6.10, U2.13 (AP_SCL/AP_SCLK), U5.15 (PA5)
SWCLK: D2.1 (K), J5.4, U5.37 (PA14)
SWDIO: D1.1 (K), J5.3, U5.34 (PA13)
UART1_RX: J6.4, U1.5 (RX), U5.30 (PA9)
UART1_TX: J6.5, U1.6 (TX), U5.31 (PA10)
USB_N: U4.6 (I/O1), U5.32 (PA11)
USB_P: U4.4 (I/O2), U5.33 (PA12)
VCC: C1.2, C2.2, C17.1, F1.2, FB2.2, J2.2, J6.2, U1.4 (VCC_5), U3.1 (VIN), U3.3 (EN), U4.5 (VBUS)
VIN: F1.1, J1.A4 (VBUS), J1.A9 (VBUS), J1.B4 (VBUS), J1.B9 (VBUS), J2.1

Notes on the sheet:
MCU
UZG1V220MCL1GB
RPLiDAR Interface
USB & Power
UZG1C470MCL1GB
Headers for Debugging
ABM3B
IMU
Crystal: ABM3B-8.000MHZ-B2-T Button: B3F-1002

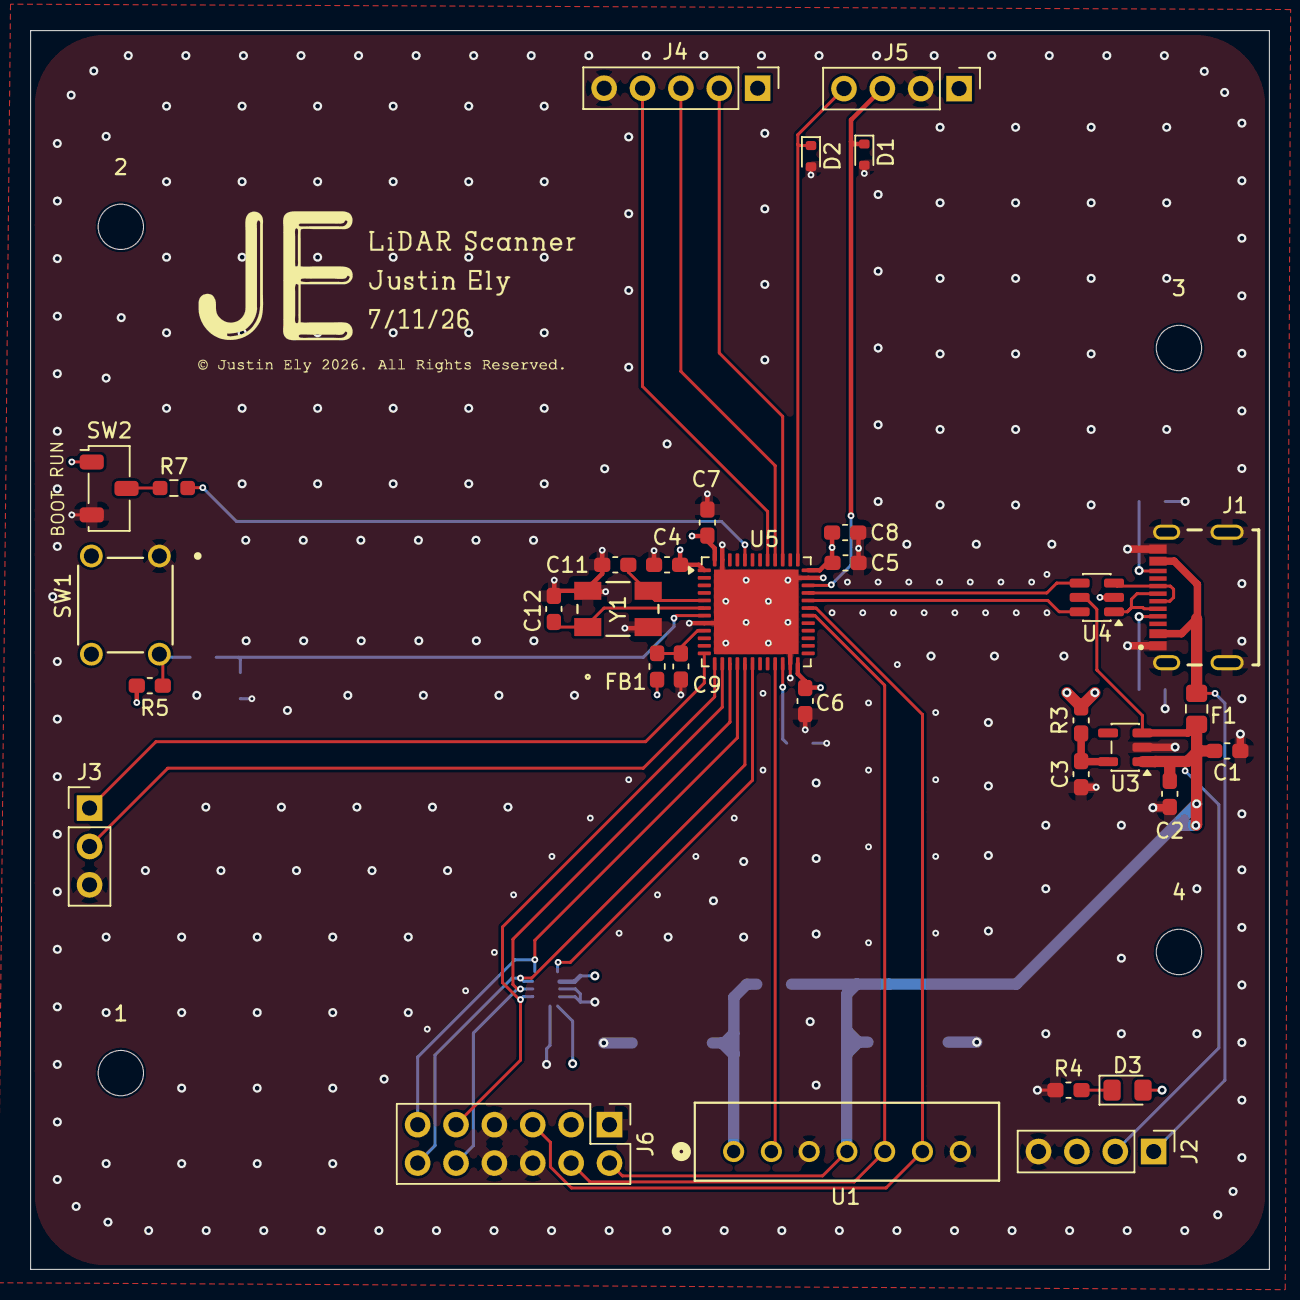
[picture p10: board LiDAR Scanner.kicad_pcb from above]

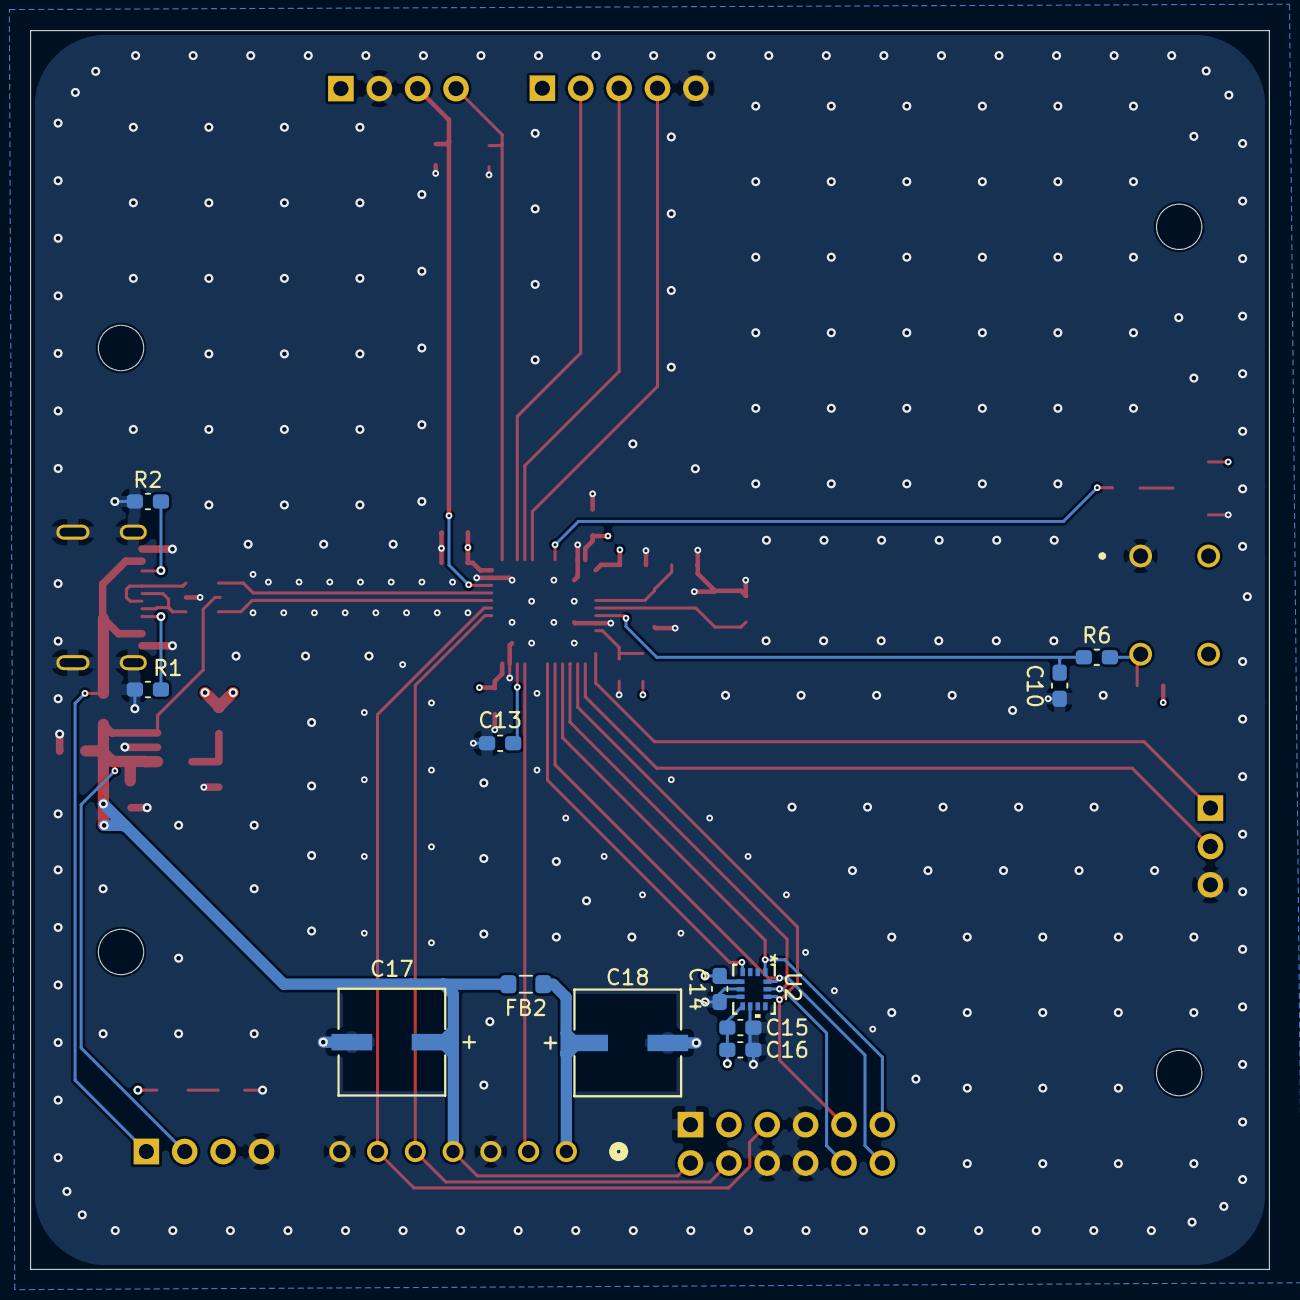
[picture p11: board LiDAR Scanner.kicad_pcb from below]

Board: 4 copper layers, 82.0 x 82.0 mm, 49 parts (12 on the bottom side), 36 nets.

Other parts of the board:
1, 2, 3, 4: MountingHole_3mm

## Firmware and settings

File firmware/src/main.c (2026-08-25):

/* ---------------------------------------------------------------------------
 * main.c -- Mini-LiDAR-Board IMU orientation firmware, milestone 1.
 *
 * What this firmware does:
 *   - brings the STM32F411CEU6 up to 96 MHz from the 8 MHz crystal, with the
 *     exact 48 MHz PLLQ that USB needs;
 *   - configures the on-board ICM-42688-P for 1 kHz accel + gyro in low-noise
 *     mode and reads it over DMA on every data-ready interrupt;
 *   - measures and removes the gyroscope's zero-rate bias at start-up;
 *   - runs a 6-DOF Madgwick filter at the full 1 kHz sample rate;
 *   - streams the resulting quaternion to the host at ~100 Hz over a
 *     bare-metal USB CDC-ACM link, in the framing described in PROTOCOL.md.
 *
 *   - drives the RPLIDAR A1 spindle with TIM2_CH3 PWM, decodes its standard
 *     SCAN stream off USART1 (circular DMA), and forwards each complete
 *     revolution to the host paired with the quaternion at ring-close time.
 *
 * What this firmware deliberately does NOT do: any 3D reconstruction.  Rings
 * are shipped in the sensor's own 2D polar frame; the quaternion travels
 * alongside them but nothing rotates anything yet.
 *
 * ---------------------------------------------------------------------------
 * A NOTE ON STATUS REPORTING
 * ---------------------------------------------------------------------------
 * This board has no GPIO-driven LEDs.  D3 is a power indicator hard-wired
 * across the 3.3 V rail; the MCU cannot touch it.  Every piece of firmware
 * state is therefore reported one of two ways:
 *   1. as a STATUS packet on the USB link (the primary channel), or
 *   2. as an edge on DEBUG_A/B/C (PB3/PB4/PB5, header J4) for a scope.
 * There is no blink code anywhere in this project, and there cannot be.
 * ------------------------------------------------------------------------- */

#include <stdbool.h>
#include <stdint.h>

#include "board.h"
#include "clock.h"
#include "debug_pins.h"
#include "icm42688.h"
#include "iwdg.h"
#include "madgwick.h"
#include "motor.h"
#include "packet.h"
#include "pkt_ring.h"
#include "rplidar.h"
#include "spi1_dma.h"
#include "tim_us.h"
#include "usart1_dma.h"
#include "usb_cdc.h"
#include "util.h"

/* ---------------------------------------------------------------------------
 * Tunables
 * ------------------------------------------------------------------------- */

/* Madgwick gain.  Madgwick's own guidance is beta = sqrt(3/4) * gyro
 * measurement error in rad/s; 0.1 corresponds to roughly 6.6 deg/s of assumed
 * gyro error, which is a good general-purpose starting point for a
 * hand-held board.  Runtime-tunable from the host (PKT_TYPE_CMD_SET_BETA). */
#define MADGWICK_BETA_DEFAULT   0.1f

/* Stream every Nth filter update.  1 kHz / 10 = 100 Hz, which is far more
 * than a screen can show and keeps the USB link at ~7 kB/s. */
#define PACKET_DECIMATION       10U

/* Gyro bias calibration: discard the first samples (the filters inside the
 * IMU are still settling), then average this many. */
#define CALIB_SETTLE_SAMPLES    200U
#define CALIB_AVERAGE_SAMPLES   2000U
/* If the board moves during calibration the average is meaningless.  Reject
 * and retry if any axis exceeds this rate, in deg/s. */
#define CALIB_MAX_RATE_DPS      5.0f
#define CALIB_MAX_ATTEMPTS      3U

/* Declare the IMU stalled if no data-ready edge arrives for this long.  At
 * 1 kHz we expect one every millisecond. */
#define IMU_STALL_TIMEOUT_US    200000U

/* Declare the LiDAR stalled if no valid measurement node arrives for this
 * long.  A healthy A1 delivers one every ~430 us. */
#define LIDAR_STALL_TIMEOUT_US  1500000U

/* Declare the SPINDLE stalled if no revolution completes for this long.
 *
 * This is a separate failure from the one above, and the one that actually
 * bit us: when the spindle stalls, the A1 keeps streaming measurement nodes
 * at a frozen angle, so the node watchdog stays happy forever while no ring
 * ever closes.  At the slowest useful spin (~2 rev/s) a revolution takes
 * 500 ms, so 3 s is comfortably clear of normal operation. */
#define SPINDLE_STALL_TIMEOUT_US  3000000U

/* How long to hold full duty when trying to break a stalled spindle free.
 * Static friction takes more torque to overcome than rotation does to
 * sustain, so a brief kick restarts a motor that will then happily run at
 * the commanded duty. */
#define SPINDLE_KICK_MS         400U

/* How long to let the spindle come up to speed before asking it to scan.
 * The A1 has no "at speed" report in standard SCAN mode, so this is an open
 * loop wait; the measured rotation rate afterwards is the real check. */
#define LIDAR_SPINUP_MS         2000U

#define DEG_TO_RAD              0.01745329252f

/* ---------------------------------------------------------------------------
 * State
 * ------------------------------------------------------------------------- */
static float    s_gyro_bias_dps[3];
static bool     s_bias_valid;
static bool     s_imu_ok;
static uint8_t  s_who_am_i;
static uint32_t s_stall_recoveries;
static uint32_t s_last_sample_t_us;
static bool     s_have_last_sample;

/* Set from the USB interrupt by the command parser, acted on in the main
 * loop so that no host command can run inside an ISR. */
static volatile bool  s_cmd_recalibrate;
static volatile bool  s_cmd_ping;
static volatile bool  s_cmd_beta_changed;

static bool     s_lidar_ok;
static bool     s_lidar_want_scan = true;
static uint32_t s_lidar_recoveries;
static uint32_t s_scan_frames_sent;

/* Set from the USB interrupt, acted on in the main loop. */
static volatile bool     s_cmd_motor_changed;
static volatile uint16_t s_cmd_motor_permille;
static volatile bool     s_cmd_decim_changed;
static volatile uint8_t  s_cmd_decim;
static volatile bool     s_cmd_lidar_enable_changed;
static volatile uint8_t  s_cmd_lidar_enable;

static uint8_t  s_frame[PKT_MAX_FRAME];

/* The scan serialiser walks the point array as interleaved uint16 pairs, so
 * the driver's point struct must be exactly that and nothing more. */
STATIC_ASSERT(sizeof(rplidar_point_t) == 4U, "rplidar_point_t must be 2 x u16");

/* ---------------------------------------------------------------------------
 * Status reporting
 * ------------------------------------------------------------------------- */
static uint8_t current_flags(void)
{
    uint8_t f = 0U;

    if (s_imu_ok)                { f |= PKT_FLAG_IMU_OK; }
    if (s_bias_valid)            { f |= PKT_FLAG_BIAS_VALID; }
    if (usb_cdc_configured())    { f |= PKT_FLAG_USB_CONFIGURED; }
    if (!s_bias_valid)           { f |= PKT_FLAG_CALIBRATING; }
    if (s_stall_recoveries > 0U) { f |= PKT_FLAG_STALL_RECOVERED; }
    if (s_lidar_ok)              { f |= PKT_FLAG_LIDAR_OK; }
    if (rplidar_is_scanning())   { f |= PKT_FLAG_LIDAR_SCANNING; }
    return f;
}

static void send_status(pkt_status_code_t code, const char *msg)
{
    pkt_status_t st;

    st.t_us      = micros();
    st.uptime_ms = millis();
    st.code      = (uint8_t)code;
    st.who_am_i  = s_who_am_i;
    st.flags     = current_flags();
    pkt_set_msg(&st, msg);

    const uint16_t n = pkt_build_status(s_frame, &st);
    (void)usb_cdc_send_frame(s_frame, n);
}

/* ---------------------------------------------------------------------------
 * Host command channel (bulk OUT).  Runs in the USB interrupt: it validates
 * the frame and records the request, and does nothing expensive.
 * ------------------------------------------------------------------------- */
static void on_usb_rx(const uint8_t *data, uint16_t len)
{
    /* Smallest possible command frame is header + CRC with no payload. */
    if (len < PKT_OVERHEAD) {
        return;
    }
    if ((data[0] != PKT_SYNC0) || (data[1] != PKT_SYNC1) || (data[2] != PKT_VERSION)) {
        return;
    }

    const uint16_t payload_len = (uint16_t)(data[4] | ((uint16_t)data[5] << 8));

    if ((uint32_t)payload_len + PKT_OVERHEAD > len) {
        return;                 /* truncated or bogus length */
    }

    const uint16_t want = pkt_crc16(&data[2], (uint16_t)(4U + payload_len));
    const uint16_t got  = (uint16_t)(data[PKT_HEADER_LEN + payload_len]
                        | ((uint16_t)data[PKT_HEADER_LEN + payload_len + 1U] << 8));

    if (want != got) {
        return;
    }

    switch (data[3]) {
    case PKT_TYPE_CMD_SET_BETA:
        if (payload_len >= 4U) {
            union { uint32_t u; float f; } conv;

            conv.u = (uint32_t)data[6]
                   | ((uint32_t)data[7] << 8)
                   | ((uint32_t)data[8] << 16)
                   | ((uint32_t)data[9] << 24);

            /* Reject NaN and absurd gains rather than poisoning the filter.
             * (x != x) is the standard NaN test without <math.h>. */
            if ((conv.f == conv.f) && (conv.f >= 0.0f) && (conv.f <= 10.0f)) {
                madgwick_set_beta(conv.f);
                s_cmd_beta_changed = true;
            }
        }
        break;

    case PKT_TYPE_CMD_RECALIBRATE:
        s_cmd_recalibrate = true;
        break;

    case PKT_TYPE_CMD_PING:
        s_cmd_ping = true;
        break;

    case PKT_TYPE_CMD_SET_MOTOR:
        if (payload_len >= 2U) {
            s_cmd_motor_permille = (uint16_t)(data[6] | ((uint16_t)data[7] << 8));
            s_cmd_motor_changed  = true;
        }
        break;

    case PKT_TYPE_CMD_SET_DECIM:
        if (payload_len >= 1U) {
            s_cmd_decim         = data[6];
            s_cmd_decim_changed = true;
        }
        break;

    case PKT_TYPE_CMD_LIDAR_ENABLE:
        if (payload_len >= 1U) {
            s_cmd_lidar_enable         = data[6];
            s_cmd_lidar_enable_changed = true;
        }
        break;

    default:
        break;
    }
}

/* ---------------------------------------------------------------------------
 * Gyro bias calibration
 *
 * Zero-rate offset, not noise, is what dominates yaw drift on a MEMS gyro: a
 * steady 1 deg/s bias is 60 degrees of error after a minute, whereas the
 * random walk is a fraction of that.  A few seconds of averaging while the
 * board sits still removes almost all of it.
 *
 * This runs before the filter starts and blocks the main loop, so it refreshes
 * the watchdog and services USB itself.
 * ------------------------------------------------------------------------- */
static bool calibrate_gyro_bias(void)
{
    for (uint32_t attempt = 0U; attempt < CALIB_MAX_ATTEMPTS; attempt++) {
        icm_sample_t s;
        float        sum[3] = { 0.0f, 0.0f, 0.0f };
        uint32_t     settled = 0U;
        uint32_t     taken   = 0U;
        bool         moved   = false;
        uint32_t     started = micros();

        while (taken < CALIB_AVERAGE_SAMPLES) {
            iwdg_refresh();
            usb_cdc_poll();

            /* Give up on this attempt if the IMU stops delivering; the caller
             * will report the failure. */
            if ((micros() - started) > 20000000UL) {
                return false;
            }

            if (!icm_pop_sample(&s)) {
                continue;
            }

            if (settled < CALIB_SETTLE_SAMPLES) {
                settled++;
                continue;
            }

            if ((s.gx > CALIB_MAX_RATE_DPS) || (s.gx < -CALIB_MAX_RATE_DPS)
             || (s.gy > CALIB_MAX_RATE_DPS) || (s.gy < -CALIB_MAX_RATE_DPS)
             || (s.gz > CALIB_MAX_RATE_DPS) || (s.gz < -CALIB_MAX_RATE_DPS)) {
                moved = true;
                break;
            }

            sum[0] += s.gx;
            sum[1] += s.gy;
            sum[2] += s.gz;
            taken++;
        }

        if (!moved && (taken == CALIB_AVERAGE_SAMPLES)) {
            s_gyro_bias_dps[0] = sum[0] / (float)CALIB_AVERAGE_SAMPLES;
            s_gyro_bias_dps[1] = sum[1] / (float)CALIB_AVERAGE_SAMPLES;
            s_gyro_bias_dps[2] = sum[2] / (float)CALIB_AVERAGE_SAMPLES;
            return true;
        }

        send_status(PKT_STATUS_CALIB_START, "board moved, retrying");
    }

    /* Out of attempts: run with no bias correction rather than refusing to
     * start.  The host is told, and the operator can ask for another go. */
    s_gyro_bias_dps[0] = 0.0f;
    s_gyro_bias_dps[1] = 0.0f;
    s_gyro_bias_dps[2] = 0.0f;
    return false;
}

static void run_calibration(void)
{
    s_bias_valid = false;
    send_status(PKT_STATUS_CALIB_START, "hold still: gyro bias cal");

    const bool ok = calibrate_gyro_bias();

    s_bias_valid = ok;
    madgwick_init(madgwick_get_beta());   /* start from identity afterwards */
    s_have_last_sample = false;

    send_status(ok ? PKT_STATUS_CALIB_DONE : PKT_STATUS_CALIB_START,
                ok ? "gyro bias captured" : "cal failed, bias = 0");
}

/* ---------------------------------------------------------------------------
 * Housekeeping callback handed to the LiDAR driver.
 *
 * rplidar_start_scan() has to wait on a device that may take half a second to
 * answer.  Rather than let that stall the watchdog and the USB link, the
 * driver calls this from inside its wait loops.  It deliberately does NOT
 * touch the IMU: samples keep queueing in the driver's own ring and are
 * drained by the main loop afterwards.
 * ------------------------------------------------------------------------- */
static void housekeeping(void)
{
    iwdg_refresh();
    usb_cdc_poll();
}

/* ---------------------------------------------------------------------------
 * One completed LiDAR revolution.  Called from rplidar_poll(), i.e. from the
 * main loop -- not from an interrupt -- so building and queueing a ~1.5 KB
 * frame here is safe.
 * ------------------------------------------------------------------------- */
static void on_lidar_ring(const rplidar_ring_t *ring)
{
    const quat_t      q = madgwick_quat();
    pkt_scan_header_t h;

    h.t_us           = ring->t_us;
    h.seq            = ring->seq;
    h.q[0]           = q.w;
    h.q[1]           = q.x;
    h.q[2]           = q.y;
    h.q[3]           = q.z;
    h.rot_hz         = rplidar_rotation_hz();
    h.sample_hz      = rplidar_sample_hz();
    h.point_count    = ring->count;
    h.motor_permille = motor_get_permille();
    h.decimation     = rplidar_get_decimation();
    h.flags          = current_flags();
    h.reserved       = 0U;

    if (ring->truncated) {
        h.flags |= PKT_FLAG_SCAN_TRUNCATED;
    }

    const uint16_t n = pkt_build_scan(s_frame, &h, (const uint16_t *)ring->pts);

    if (n != 0U) {
        DEBUG_C_TOGGLE();
        (void)usb_cdc_send_frame(s_frame, n);
        s_scan_frames_sent++;
    }
}
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
int main(void)
{
    if (!clock_init()) {
        /* Without the crystal there is no 48 MHz for USB and no way to report
         * anything.  Reset and try again; a genuinely dead crystal turns into
         * a boot loop, which is at least diagnosable with a scope on PH0. */
        NVIC_SystemReset();
    }

    tim_us_init();
    debug_pins_init();
    pkt_ring_init();

    madgwick_init(MADGWICK_BETA_DEFAULT);

    /* USB comes up before the IMU so that an IMU failure can be reported over
     * the link.  Frames queued before enumeration completes simply sit in the
     * ring buffer (oldest discarded on overflow) until the host attaches. */
    usb_cdc_set_rx_callback(on_usb_rx);
    usb_cdc_init();

    spi1_init();

    send_status(PKT_STATUS_BOOT, "boot: 96 MHz, USB up");

    s_imu_ok = bring_up_imu();

    /* ---- Gyro bias calibration happens BEFORE the spindle starts ---------
     * The calibration averages the gyro while the board is supposed to be
     * still, and rejects the attempt if any axis exceeds a few deg/s.  A
     * spinning LiDAR motor couples real vibration into the IMU, which would
     * either bias the average or trip the motion rejection.  So: calibrate
     * first, spin second. */
    if (s_imu_ok) {
        run_calibration();
    }

    /* ---- LiDAR -----------------------------------------------------------
     * Spin the spindle up, give it a couple of seconds to reach speed, then
     * ask the device to scan.  The motor supply is hard-wired on, so the PWM
     * duty is the only control we have. */
    motor_init();
    usart1_init();
    rplidar_init(on_lidar_ring, housekeeping);

    motor_set_permille(MOTOR_PERMILLE_DEFAULT);

    for (uint32_t i = 0U; i < LIDAR_SPINUP_MS; i++) {
        delay_ms(1U);
        usb_cdc_poll();
    }

    s_lidar_ok = bring_up_lidar();

    /* Start the watchdog only once all the slow, blocking init is finished. */
    iwdg_init();

    uint32_t decim = 0U;
    uint32_t last_stall_check_us = micros();

    uint32_t last_lidar_check_us = micros();

    for (;;) {
        iwdg_refresh();
        usb_cdc_poll();

        /* ---- Drain every sample the ISRs have queued -------------------- */
        icm_sample_t s;

        while (icm_pop_sample(&s)) {
            process_sample(&s, &decim);
        }

        /* ---- Drain the LiDAR UART and emit any completed revolution -----
         * Deliberately after the IMU: the quaternion paired with a ring
         * should be as fresh as possible at the moment the ring closes. */
        rplidar_poll();

        /* ---- Host commands ---------------------------------------------- */
        if (s_cmd_ping) {
            s_cmd_ping = false;
            send_status(PKT_STATUS_PONG, "pong");
        }
        if (s_cmd_beta_changed) {
            s_cmd_beta_changed = false;
            send_status(PKT_STATUS_BETA_CHANGED, "beta updated");
        }
        if (s_cmd_recalibrate) {
            s_cmd_recalibrate = false;
            if (s_imu_ok) {
                run_calibration();
            }
        }
        if (s_cmd_motor_changed) {
            s_cmd_motor_changed = false;
            motor_set_permille(s_cmd_motor_permille);
            send_status(PKT_STATUS_MOTOR_CHANGED, "motor duty updated");
        }
        if (s_cmd_decim_changed) {
            s_cmd_decim_changed = false;
            rplidar_set_decimation(s_cmd_decim);
            send_status(PKT_STATUS_DECIM_CHANGED, "decimation updated");
        }
        if (s_cmd_lidar_enable_changed) {
            s_cmd_lidar_enable_changed = false;
            s_lidar_want_scan = (s_cmd_lidar_enable != 0U);

            if (s_lidar_want_scan) {
                s_lidar_ok = bring_up_lidar();
            } else {
                rplidar_stop_scan();
                s_lidar_ok = false;
                send_status(PKT_STATUS_LIDAR_STOPPED, "scan stopped by host");
            }
        }

        /* ---- IMU stall detection and recovery ---------------------------
         * If INT1 stops pulsing -- a glitched configuration write, a brown-out
         * on the IMU rail, a stuck DMA -- re-initialise the device rather than
         * streaming a frozen quaternion forever.  Checked at 10 Hz so the
         * happy path costs nothing. */
        if ((micros() - last_stall_check_us) > 100000UL) {
            last_stall_check_us = micros();

            if ((micros() - icm_last_drdy_us()) > IMU_STALL_TIMEOUT_US) {
                send_status(PKT_STATUS_IMU_STALL, "no IMU data-ready");

                icm_irq_disable();
                if (bring_up_imu()) {
                    s_stall_recoveries++;
                    s_have_last_sample = false;
                    send_status(PKT_STATUS_IMU_RECOVERED, "IMU re-initialised");
                }
                /* Whether or not recovery worked, the loop keeps running and
                 * keeps refreshing the watchdog, so the link stays alive and
                 * the host keeps seeing status packets. */
            }
        }

        /* ---- LiDAR stall detection and recovery -------------------------
         * Only meaningful while we are supposed to be scanning AND the motor
         * is actually commanded to turn: a deliberately stopped spindle
         * produces no nodes, and that is not a fault. */
        if ((micros() - last_lidar_check_us) > 500000UL) {
            last_lidar_check_us = micros();

            const bool should_be_running =
                s_lidar_want_scan && (motor_get_permille() >= MOTOR_PERMILLE_MIN_RUN);

            /* (a) The device has gone quiet altogether. */
            const bool nodes_dead = should_be_running
                && ((micros() - rplidar_last_node_us()) > LIDAR_STALL_TIMEOUT_US);

            /* (b) The device is still talking but the spindle is not turning.
             * Nodes keep arriving at a frozen angle, so (a) never fires. */
            const bool spindle_dead = should_be_running && rplidar_is_scanning()
                && ((micros() - rplidar_last_ring_us()) > SPINDLE_STALL_TIMEOUT_US);

            if (nodes_dead || spindle_dead) {
                send_status(PKT_STATUS_LIDAR_STALL,
                            spindle_dead ? "spindle stalled: no revolutions"
                                         : "no LiDAR measurements");

                if (spindle_dead) {
                    /* Kick the motor to full duty briefly to break static
                     * friction, then hand it back the commanded duty. */
                    const uint16_t want = motor_get_permille();

                    motor_set_permille(MOTOR_PERMILLE_MAX);
                    for (uint32_t i = 0U; i < SPINDLE_KICK_MS; i++) {
                        delay_ms(1U);
                        iwdg_refresh();
                        usb_cdc_poll();
                    }
                    motor_set_permille(want);
                }

                usart1_init();               /* re-arm the DMA from scratch  */
                if (bring_up_lidar()) {
                    s_lidar_recoveries++;
                    send_status(PKT_STATUS_LIDAR_RECOVERED, "LiDAR restarted");
                }
            }
        }
    }
}

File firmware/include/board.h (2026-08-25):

/* ---------------------------------------------------------------------------
 * board.h -- Mini-LiDAR-Board hardware description.
 *
 * Every pin assignment in this file was read out of the project's KiCad
 * netlist ("LiDAR Scanner.kicad_sch" / ".kicad_pcb"), not out of the project
 * write-up.  Where the two disagree, the KiCad files win.  See HARDWARE.md for
 * the list of places where the older project guide is wrong.
 *
 * MCU : STM32F411CEU6, UFQFPN-48, 512 KiB flash / 128 KiB SRAM
 * XTAL: 8 MHz HSE on PH0/PH1 (Y1, 22 pF load caps).  There is NO 32.768 kHz
 *       LSE crystal on this board.
 * ------------------------------------------------------------------------- */

#ifndef BOARD_H
#define BOARD_H

#include "stm32f411xe.h"

/* ---------------------------------------------------------------------------
 * Clock tree (see clock.c for the derivation and the RM0383 constraints)
 * ------------------------------------------------------------------------- */
#define BOARD_HSE_HZ      8000000UL   /* Y1                                    */
#define BOARD_SYSCLK_HZ   96000000UL  /* PLL P output                          */
#define BOARD_AHB_HZ      96000000UL  /* AHB prescaler /1                      */
#define BOARD_APB1_HZ     48000000UL  /* APB1 /2  -- must stay <= 50 MHz       */
#define BOARD_APB2_HZ     96000000UL  /* APB2 /1  -- limit is 100 MHz          */
#define BOARD_APB1_TIM_HZ 96000000UL  /* APB1 timers run at 2x PCLK1 (/2 pre)  */
#define BOARD_USB48_HZ    48000000UL  /* PLL Q output, exact 48 MHz for OTG_FS */

/* ---------------------------------------------------------------------------
 * IMU: U2, InvenSense/TDK ICM-42688-P, LGA-14, SPI only.
 *
 *   VDD and VDDIO are both on the 3.3 V rail.
 *   Pin 9 (INT2/FSYNC/CLKIN) is HARD-TIED TO GND on this board, so INT2 and
 *   FSYNC are unavailable -- INT1 on PB0 is the only interrupt path.  The
 *   driver must therefore never configure INT2 as a push-pull output.
 * ------------------------------------------------------------------------- */
#define IMU_CS_PORT     GPIOA
#define IMU_CS_PIN      4U            /* PA4, software-driven chip select      */
#define IMU_SCK_PIN     5U            /* PA5, SPI1_SCK,  AF5                   */
#define IMU_MISO_PIN    6U            /* PA6, SPI1_MISO, AF5                   */
#define IMU_MOSI_PIN    7U            /* PA7, SPI1_MOSI, AF5                   */
#define IMU_INT_PORT    GPIOB
#define IMU_INT_PIN     0U            /* PB0, ICM-42688-P INT1 -> EXTI0        */

/* ---------------------------------------------------------------------------
 * USB: USB-C connector on the OTG_FS full-speed PHY.
 *
 *   PA9 (the OTG_FS VBUS sense pin) is wired to the LiDAR UART instead, so
 *   VBUS sensing MUST be disabled in GCCFG (NOVBUSSENS = 1).  See usb_cdc.c.
 * ------------------------------------------------------------------------- */
#define USB_DM_PIN      11U           /* PA11, USB_OTG_FS_DM, AF10             */
#define USB_DP_PIN      12U           /* PA12, USB_OTG_FS_DP, AF10             */

/* ---------------------------------------------------------------------------
 * Debug UART: header J3 (1 = TX, 2 = RX, 3 = GND), USART2, 921600 8N1.
 *
 * NOT IMPLEMENTED IN THIS MILESTONE.  These defines record the wiring only --
 * no USART2 driver exists yet, and the firmware leaves PA2/PA3 in their reset
 * state.  All telemetry and status reporting goes over USB CDC instead.  Kept
 * here so a printf-style side channel can be added without re-reading the
 * netlist.
 * ------------------------------------------------------------------------- */
#define DBGUART_TX_PIN  2U            /* PA2, USART2_TX, AF7                   */
#define DBGUART_RX_PIN  3U            /* PA3, USART2_RX, AF7                   */
#define DBGUART_BAUD    921600UL

/* ---------------------------------------------------------------------------
 * Scope/logic-analyser header J4.  These are the ONLY visual indicators this
 * board has -- there are NO GPIO status LEDs (D3 is a bare power LED wired
 * across 3V3 through R4, with no MCU connection at all).
 * ------------------------------------------------------------------------- */
#define DEBUG_PORT      GPIOB
#define DEBUG_A_PIN     3U            /* PB3 -- toggled on each IMU sample     */
#define DEBUG_B_PIN     4U            /* PB4 -- toggled on each Madgwick step  */
#define DEBUG_C_PIN     5U            /* PB5 -- toggled on each packet TX      */

/* ---------------------------------------------------------------------------
 * SWD programming header J5: 1 = 3V3, 2 = GND, 3 = SWDIO (PA13), 4 = SWCLK
 * (PA14).  Left in their reset state; the firmware never touches PA13/PA14.
 * ------------------------------------------------------------------------- */
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

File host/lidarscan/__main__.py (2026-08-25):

"""Entry point:  python3 -m lidarscan [options]

Examples::

    python3 -m lidarscan                       # auto-detect the board
    python3 -m lidarscan --port /dev/cu.usbmodem14201
    python3 -m lidarscan --sim                 # no hardware needed
    python3 -m lidarscan --sim --duration 8    # runs 8 s then exits
    python3 -m lidarscan --sim --headless --save shot.png
    python3 -m lidarscan --selftest            # protocol round-trip checks
"""

from __future__ import annotations

import argparse
import math
import sys
import time

import numpy as np

from . import protocol as proto
from .reader import SerialSource, SimSource, find_serial_port


def build_parser() -> argparse.ArgumentParser:
    ap = argparse.ArgumentParser(
        prog="python3 -m lidarscan",
        description="Live 3D orientation viewer for the Mini-LiDAR-Board.")

    src = ap.add_argument_group("source")
    src.add_argument("--sim", action="store_true",
                     help="synthesise packets instead of reading hardware")
    src.add_argument("--port", metavar="PATH",
                     help="serial device (default: first /dev/cu.usbmodem*)")
    src.add_argument("--baud", type=int, default=115200,
                     help="ignored by USB CDC, but pyserial wants a number")
    src.add_argument("--sim-rate", type=float, default=100.0, metavar="HZ",
                     help="simulated packet rate (default 100)")
    src.add_argument("--sim-corrupt", type=int, default=0, metavar="N",
                     help="corrupt every Nth simulated frame, to exercise the "
                          "CRC/resync path (0 = never)")
    src.add_argument("--sim-drop", type=int, default=0, metavar="N",
                     help="drop every Nth simulated frame, to exercise the "
                          "loss statistic (0 = never)")

    disp = ap.add_argument_group("display")
    disp.add_argument("--fps", type=float, default=30.0,
                      help="redraw rate (default 30)")
    disp.add_argument("--duration", type=float, metavar="SECONDS",
                      help="exit automatically after this long")
    disp.add_argument("--headless", action="store_true",
                      help="render with the Agg backend and open no window")
    disp.add_argument("--save", metavar="PNG",
                      help="write a PNG of the final frame")

    rec = ap.add_argument_group("3D reconstruction")
    rec.add_argument("--cloud", action="store_true",
                     help="show the accumulated 3D point cloud instead of the "
                          "2D ring view")
    rec.add_argument("--voxel-mm", type=float, default=50.0, metavar="MM",
                     help="voxel grid size for thinning the cloud "
                          "(default 50)")
    rec.add_argument("--max-points", type=int, default=60000, metavar="N",
                     help="point budget; oldest voxels are recycled past this "
                          "(default 60000)")
    rec.add_argument("--range-m", type=float, default=6.0, metavar="M",
                     help="half-size of the displayed cube (default 6)")
    rec.add_argument("--lidar-yaw-deg", type=float, default=0.0, metavar="DEG",
                     help="mechanical yaw of the LiDAR relative to the board's "
                          "forward axis")
    rec.add_argument("--lidar-ccw", action="store_true",
                     help="LiDAR angle advances counter-clockwise seen from "
                          "above (flip if the cloud is mirrored)")
    rec.add_argument("--save-ply", metavar="PATH",
                     help="write the accumulated cloud to a PLY file on exit")
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

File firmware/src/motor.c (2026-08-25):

/* ---------------------------------------------------------------------------
 * motor.c -- see motor.h.
 *
 * Timer clock arithmetic:
 *   TIM2 sits on APB1.  APB1's prescaler is /2, and the STM32 doubles the
 *   timer clock whenever the APB prescaler is not /1, so TIM2 counts at
 *   2 x 48 MHz = 96 MHz (RM0383 6.2, "Clock tree").
 *
 *   PSC = 0, ARR = 4799  ->  96 MHz / 4800 = 20 kHz PWM
 *
 *   4800 counts of resolution across a 0-1000 permille control range is far
 *   finer than the spindle can actually respond to, so the duty arithmetic
 *   below never needs to worry about rounding.
 * ------------------------------------------------------------------------- */

#include "motor.h"
#include "board.h"

#define MOTOR_PWM_ARR   4799UL          /* 20 kHz from a 96 MHz timer clock  */

static uint16_t s_permille;

void motor_init(void)
{
    /* ---- GPIO: PB10 -> AF1 (TIM2_CH3), push-pull -------------------------
     * Deliberately left at LOW speed: this is a 20 kHz signal into a motor
     * driver, and a slow edge radiates far less into the SPI and UART traces
     * running nearby.  The project's layout notes call this out explicitly. */
    RCC->AHB1ENR |= RCC_AHB1ENR_GPIOBEN;

    const uint32_t pin = LIDAR_PWM_PIN;
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

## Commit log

2026-06-16 using github for backup
    [LiDAR Scanner.kicad_pcb, LiDAR Scanner.kicad_sch]
2026-06-26 finished v1 schematic
    [LiDAR Scanner.kicad_sch]
2026-07-11 Added stitching vias, electrolytic caps, final design
    [LiDAR Scanner.kicad_pcb, LiDAR Scanner.kicad_sch]
2026-07-27 Finalized board + gerbers
    [LiDAR Scanner-B_Cu.gbl, LiDAR Scanner-B_Mask.gbs, LiDAR Scanner-B_Paste.gbp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]
2026-09-04 fixed stitching vias
    [LiDAR Scanner.kicad_pcb]
2026-09-14 Froze v1, working on v2 now
    [LiDAR Scanner-B_Cu.gbr, LiDAR Scanner-B_Mask.gbr, LiDAR Scanner-B_Paste.gbr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]
2026-10-08 Added more detailed photos
    [LiDAR Scanner.kicad_pcb]
